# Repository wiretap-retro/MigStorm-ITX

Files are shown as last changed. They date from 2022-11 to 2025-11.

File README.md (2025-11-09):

# MigStorm-ITX
A 68000 socketed ITX form factor Minimig.

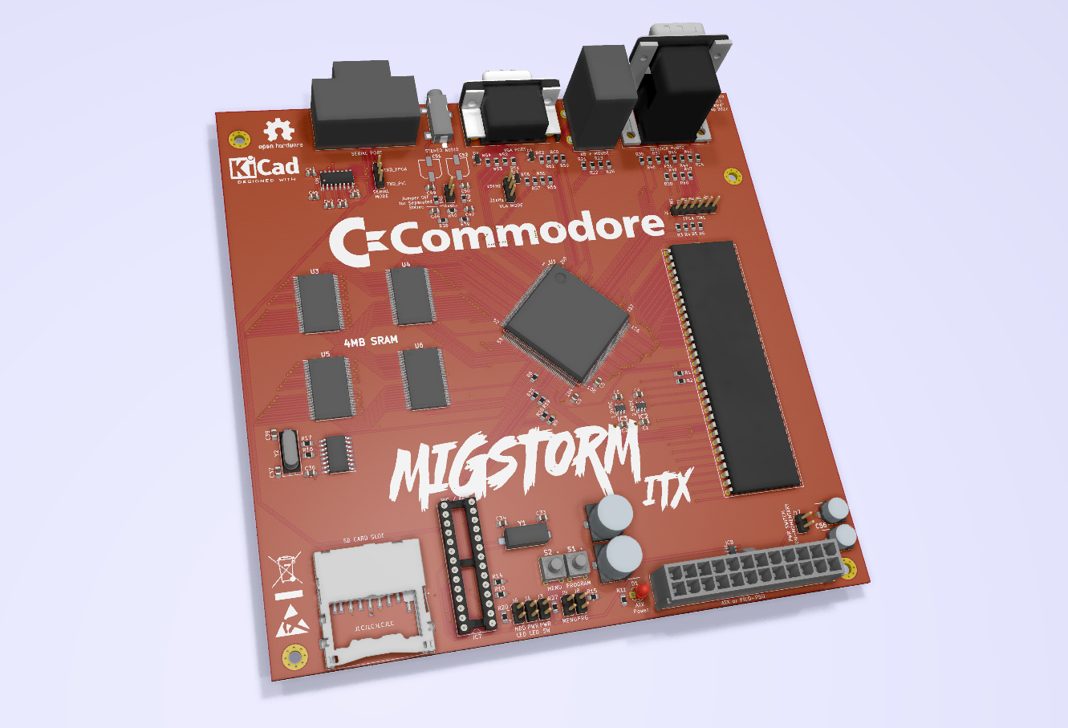
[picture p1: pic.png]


## Info
Tested by Zenon to boot with Pistorm and CaffeineOS, also with a regular M68k CPU. It appears to be fully working, and I've received feedback from at least 10 people that it is working well in their testing. It could use more general trace cleanup/enhancement, but works as-is.

## Mouser Cart
https://www.mouser.com/ProjectManager/ProjectDetail.aspx?AccessID=da74540bb5 \
At the time of making the Mouser cart, all parts were in stock. If parts go out of stock, EOL, have a part number change, or have a minimum order quantity change -- seach for equivalent replacements or they may be able to be sourced from Arrow and Digikey. I recommend using Octopart and other similar sites to search for parts if you can't find something. I caution using sources like Ebay and Aliexpress for key components, especially from China-based sellers with little to no feedback since they'll often sell counterfeit items. Sometimes you get lucky, sometimes you don't. Primary/authorized retailers are highly recommended for component purchases so you do less troubleshooting and can spend more time playing. \
\
As a DIY project, total cost for all parts and a board should come out to just under $150. (plus the cost of a CPU/Pistorm, power supply, and case) \
\
An interactive HTML BOM has been added to the main repository to assist with building.

## Other / Misc. Contributions
jjsaenz1969's 3D printed case for Migstorm: https://www.thingiverse.com/thing:7063501

## Rev History
v0.6 -- Current rev to build. Updated PS/2 Mouse & Keyboard to use redundant clock & data lines due to issues with some keyboards and mice using splitter style pinout. \
v0.5 -- Updated silkscreen for capacitor polarity upon community request. Updated iBOM and BOM. \
v0.4 -- Corrected PS/2 Mouse & Keyboard pwr/gnd pinout. \
v0.3 -- Changed soft-power circuit from 555 timer to a MAX16054, cleaned up a few traces with lots of vias. Still need more cleanup. [depreciated rev, do not build] \
v0.2 -- Initial rev with corrected 68k socket size. [depreciated rev, do not build] \
v0.1 -- Alpha release, incorrect 68k footprint width. [depreciated, removed]

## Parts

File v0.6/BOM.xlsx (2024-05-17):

MigStorm v0.6 Bill of Materials
Reference | Quantity | Value | Footprint | Description | Manufacturer Name | Manufacturer Part Number | Note
C1 C4 C2 C5 | 4 | 1uF X5R | Capacitor_SMD:C_0805_2012Metric_Pad1.15x1.40mm_HandSolder
C14 C16 C18 C20 C13 C15 C17 C19 C3 C6 C7 C8 C9 C10 C11 C12 C23 C24 C46 C47 C49 C50 | 22 | 10nF | Capacitor_SMD:C_0805_2012Metric_Pad1.15x1.40mm_HandSolder
C22 C21 C26 C27 C28 C25 C30 C31 C32 C29 C41 C36 C45 C48 C42 C43 C44 | 17 | 100nF | Capacitor_SMD:C_0805_2012Metric_Pad1.15x1.40mm_HandSolder
C33 C34 | 2 | 47pf | Capacitor_SMD:C_0805_2012Metric_Pad1.15x1.40mm_HandSolder
C37 | 1 | 100pF | Capacitor_SMD:C_0805_2012Metric_Pad1.15x1.40mm_HandSolder
C39 | 1 | 22pF | Capacitor_SMD:C_0805_2012Metric_Pad1.15x1.40mm_HandSolder
C51 C52 | 2 | 16SVT100M | 16SVPT100M | Aluminium Organic Polymer Capacitors 16VDC 100uF 20% 780mA 24mOhm | Panasonic | 16SVT100M
C54 C53 | 2 | 470uF | CAPAE1030X1050N | Wurth Elektronik 470uF 10 V dc Aluminium Electrolytic Capacitor, WCAP-AS5H Series 5000h 10.5 (Dia.) x 9.85mm | Wurth Elektronik | 865230257007
C55 C56 | 2 | 100uF | CAPAE660X550N | Wurth Elektronik 100uF 6.3 V dc Aluminium Electrolytic Capacitor, WCAP-AS5H Series 5000h 5.5 (Dia.) x 6.15mm | Wurth Elektronik | 865230143004
D1 | 1 | BrdPwr | LED_THT:LED_D3.0mm
D6 D5 D2 D3 D4 | 5 | BAV99 | Package_TO_SOT_SMD:SOT-23
IC1 | 1 | SN74HC4060NSR | SOIC127P780X200-16N | 14-Stage Asynchronous Binary Counters And Oscillators | Texas Instruments | SN74HC4060NSR
IC2 | 1 | MIC5504-2.5YM5-TR | SOT95P280X145-5N | LDO Voltage Regulators Single 300mA LDO with Enable Pull-Down & Auto Discharge | Microchip | MIC5504-2.5YM5-TR
IC3 | 1 | TPS731125DBVR | SOT95P280X145-5N | Cap-Free, NMOS, 150mA Low-Dropout (LDO) Regulator With Reverse Current Protection | Texas Instruments | TPS731125DBVR
IC4 IC5 IC6 | 3 | SN74CBTD16210DGGR | SOP50P810X120-48N | SN74CBTD16210DGGR, Bus Switch 74CBT, 10 x 1:1, 4.5 5.5 V 48-Pin TSSOP | Texas Instruments | SN74CBTD16210DGGR
IC7 | 1 | PIC18F26K20-I_SP | Package_DIP:DIP-28_W7.62mm_Socket | Microchip PIC18F26K20-I/SP, 8bit PIC Microcontroller, 64MHz, 64 kB, 1024 B Flash, 28-Pin SPDIP | Microchip | PIC18F26K20-I/SP
IC8 | 1 | MAX16054AZT+T | SOT95P275X110-6N | On Off Controller, Debounce, 15kV ESD MAX16054AZT+T, Voltage Supervisor No Push Button Controller 6-Pin SOT-23 | Maxim Integrated | MAX16054AZT+T
J1 | 1 | JTAG | Connector_PinHeader_2.54mm:PinHeader_1x06_P2.54mm_Vertical
J10 | 1 | Serial | Connector_PinHeader_2.54mm:PinHeader_1x03_P2.54mm_Vertical
J11 | 1 | 500998-0900 | 5009980900 | 9 way normal mount SD card connector 9 way normal mount SD card connector | Molex | 500998-0900
J12 | 1 | Audio | Connector_PinHeader_2.54mm:PinHeader_1x02_P2.54mm_Vertical
J13 | 1 | 178-009-613R571 | 178-009-613R571
J14 | 1 | L77SDE09S1ACO4R | L77SDE09S1ACO4R | D-Sub Standard Connectors Dsub, Stamped Signal 3A, Right Angle PCB Thru Hole, FP=10.40mm (.409in), Row Pitch 2.54mm, 09 Socket, Flash Gold, Bright Tin Shell, 4-40 Rear Insert, Ground Tab with Clear Hole Without Boardlock | Amphenol | L77SDE09S1ACO4R
J15 | 1 | SJ-3523-SMT-TR | SJ3523SMTTR | Phone Connectors Audio Jacks | CUI Inc. | SJ-3523-SMT-TR
J16 | 1 | L77HDE15SD1CH4RHNVGA | L77HDE15SD1CH4RHNVGA | D-Sub High Density Connectors Dsub, Stamped Signal 3A, High Density, Right Angle PCB Thru Hole, FP=8.89mm (.350) | Bright Tin Shell | L77HDE15SD1CH4RHNVGA
J17 | 1 | ON-OFF | Connector_PinHeader_2.54mm:PinHeader_1x02_P2.54mm_Vertical
J2 | 1 | 87427-2442 | 87427-2442 | Mini-Fit Jr. Header, 4.20mm Pitch, Vertical, without Flange, 24 Circuits, Tin (Sn) over Nickel (Ni) Plating, Bulk Packaging | Molex | 87427-2442
J3 | 1 | PWRSWCH | Connector_PinHeader_2.54mm:PinHeader_1x02_P2.54mm_Vertical
J4 | 1 | PWRLED | Connector_PinHeader_2.54mm:PinHeader_1x02_P2.54mm_Vertical
J5 | 1 | Video Mode | Connector_PinHeader_2.54mm:PinHeader_1x03_P2.54mm_Vertical
J6 | 1 | DISKLED | Connector_PinHeader_2.54mm:PinHeader_1x02_P2.54mm_Vertical
J7 | 1 | KMDGX-6S_6S-S4N1 | KMDGX6S6SS4N1 | Circular DIN Connectors MINI-DIN PANEL MNT 6P SNAP&LOCK 1270 W | Kycon | KMDGX-6S/6S-S4N1
J8 | 1 | PROGRAM | Connector_PinHeader_2.54mm:PinHeader_1x02_P2.54mm_Vertical
J9 | 1 | MENU | Connector_PinHeader_2.54mm:PinHeader_1x02_P2.54mm_Vertical
R1 R2 R16 R52 R56 R60 | 6 | 2.2k | Resistor_SMD:R_0805_2012Metric_Pad1.15x1.40mm_HandSolder
R11 R40 R29 R63 R53 R57 R61 | 7 | 1k | Resistor_SMD:R_0805_2012Metric_Pad1.15x1.40mm_HandSolder
R15 R14 R10 R24 R51 R55 R59 | 7 | 4.7k | Resistor_SMD:R_0805_2012Metric_Pad1.15x1.40mm_HandSolder
R17 | 1 | 1M | Resistor_SMD:R_0805_2012Metric_Pad1.15x1.40mm_HandSolder
R19 R20 | 2 | 330 | Resistor_SMD:R_0805_2012Metric_Pad1.15x1.40mm_HandSolder
R3 R4 R6 R5 R33 R65 | 6 | 100 | Resistor_SMD:R_0805_2012Metric_Pad1.15x1.40mm_HandSolder
R38 R39 R41 R42 R54 R58 R62 | 7 | 560 | Resistor_SMD:R_0805_2012Metric_Pad1.15x1.40mm_HandSolder
R64 | 1 | 180 | Resistor_SMD:R_0805_2012Metric_Pad1.15x1.40mm_HandSolder
R7 R8 R9 R25 R26 R27 R21 R22 R28 R23 R43 R44 R45 R46 R34 R35 R36 R37 R47 R48 R49 R50 R30 R31 R32 | 25 | 270 | Resistor_SMD:R_0805_2012Metric_Pad1.15x1.40mm_HandSolder
S1 S2 | 2 | FSM4JH | FSM4JH | 6x6mm tactile switch,5mm H 1.6N Black Button Tactile Switch, SPST-NO 50 mA@ 24 V dc 1.4mm | TE Connectivity | FSM4JH
U1 | 1 | XC3S400-4PQ208C | QFP50P3060X3060X410-208N | FPGA - Field Programmable Gate Array 400000 SYSTEM GATE 1.2 VOLT FPGA | XILINX | XC3S400-4PQ208C
U2 | 1 | 68000D | Package_DIP:DIP-64_W22.86mm_Socket
U3 U5 U4 U6 | 4 | IS62WV51216EBLL-45TLI | SOP80P1176X120-44N | SRAM Chip Async Single 2.5V/3.3V 8M-bit 512K x 16 45ns 44-Pin TSOP-II | Integrated Silicon Solution Inc. | IS62WV51216EBLL-45TLI
U8 | 1 | SP3232EUCN | Package_SO:SOIC-16_3.9x9.9mm_P1.27mm
Y1 | 1 | 20 MHz | LFXTAL020423CUTT | Crystals 20MHz 22pF -20C 70C | IQD | LFXTAL035939Reel
Y2 | 1 | 4.433619 MHz | Crystal:Crystal_SMD_HC49-SD |  |  | ABLS-4.433619MHZ-B4-T

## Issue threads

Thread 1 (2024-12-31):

Unable to load the Core in my MigStorm

jjsaenz1969, 2024-12-31:
Thank you very much for all your work, this project is fantastic.
I have asked JLCPCB to manufacture your board, the BOM I have ordered the one you recommend on GitHub. And the memory and FPGA are from AliExpress.

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

My problem is that with the Pic and Core code you have on GitHub I get a black screen.
Whereas if I try other combinations of files downloaded from other sites it starts to load the Core.
But it never loads the whole Core.

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

To program the pic I use the TL866II programmer with this combination of fuses.

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

The file ‘firstflash_bootloader+KGL140914.hex’ you have on Github is empty, it would be nice if you can put the correct one.

Let's see if I can get this new Amiga working.

wiretap-retro, 2024-12-31:
You're going to want to use the tinybld198 folder for generating the PIC's firmware to flash with the firmware.hex file. The KGL140914 is for the SuperPIC. I've updated the firmware folder to include all variants of the PIC/SuperPIC/ARM modules.

jjsaenz1969, 2024-12-31:
Thank you for your prompt response.
I have the SuperPIC, then I will try what you have posted on Github.
Hopefully we'll finish this year with one more Amiga.

jjsaenz1969, 2025-01-18:
Thank you for your advice.
I had a hard time finding it, but I remembered I had one.
I've never used it before, it was easy.

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

I was able to burn the chip with the file ‘firstflash_bootloader+KGL140914.hex’, but the result is the same.
It loads the Core but does not start the Minimig.

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

The PacMan Core works perfectly, so I have a fault in the RAM or in the CPU.

Next I'll remove the CPU socket and check the chips underneath.

wiretap-retro, 2025-01-19:
Yeah you'll want to check all orientations of the chips, and use a small sewing needle to wiggle each leg of each chip to make sure they are all soldered down right. Also check for bridges between legs. Sometimes they're really hard to spot without good magnification.

jjsaenz1969, 2025-01-31:
I have good news.

I have checked the chips that are under the CPU, for this I created a new interactive BOM, but indicating that it shows the pads and tracks.
All correct there.
I also bought new RAM, this is from Mouser, the one I had before I bought from Aliexpress.

The unsoldered chip is Mouser's.
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

I have also checked every pin on the FPGA and everything is OK.
It's always the same, it always freezes at the same point.

My PIStorm is not the normal one, it is an edition that was made in a Spanish forum, it is a bit displaced so as not to touch with the keyboard on an A500.
I couldn't put it directly on the MigStorm as it clashed with the PicoPSU.
Today I got a CPU relocator, I just put it in, plugged my PIStorm and it started working.

The ARM module also works.

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

Everything works very well, I'm very happy.
But I don't know why my MigStorm only works if it has a PIStorm on it.
I don't have a different accelerator to test.

wiretap-retro, 2025-01-31:
I'm so glad to see you got it working. That's very good news. Hopefully you enjoy it!

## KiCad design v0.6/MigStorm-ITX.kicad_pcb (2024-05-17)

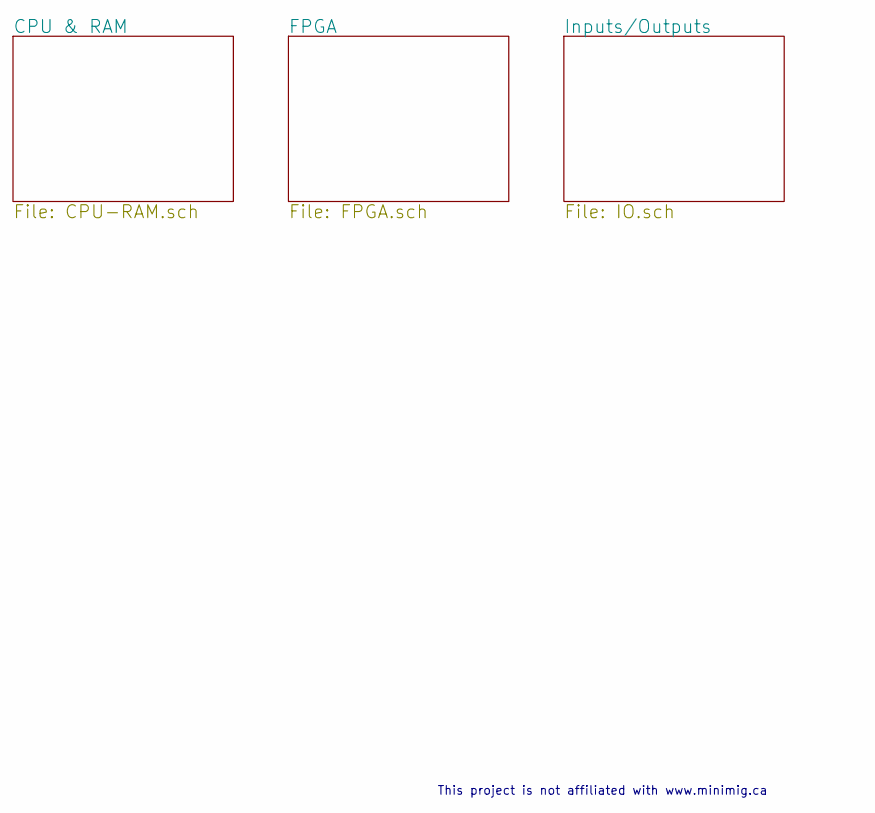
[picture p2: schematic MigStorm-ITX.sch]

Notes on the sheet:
This project is not affiliated with www.minimig.ca

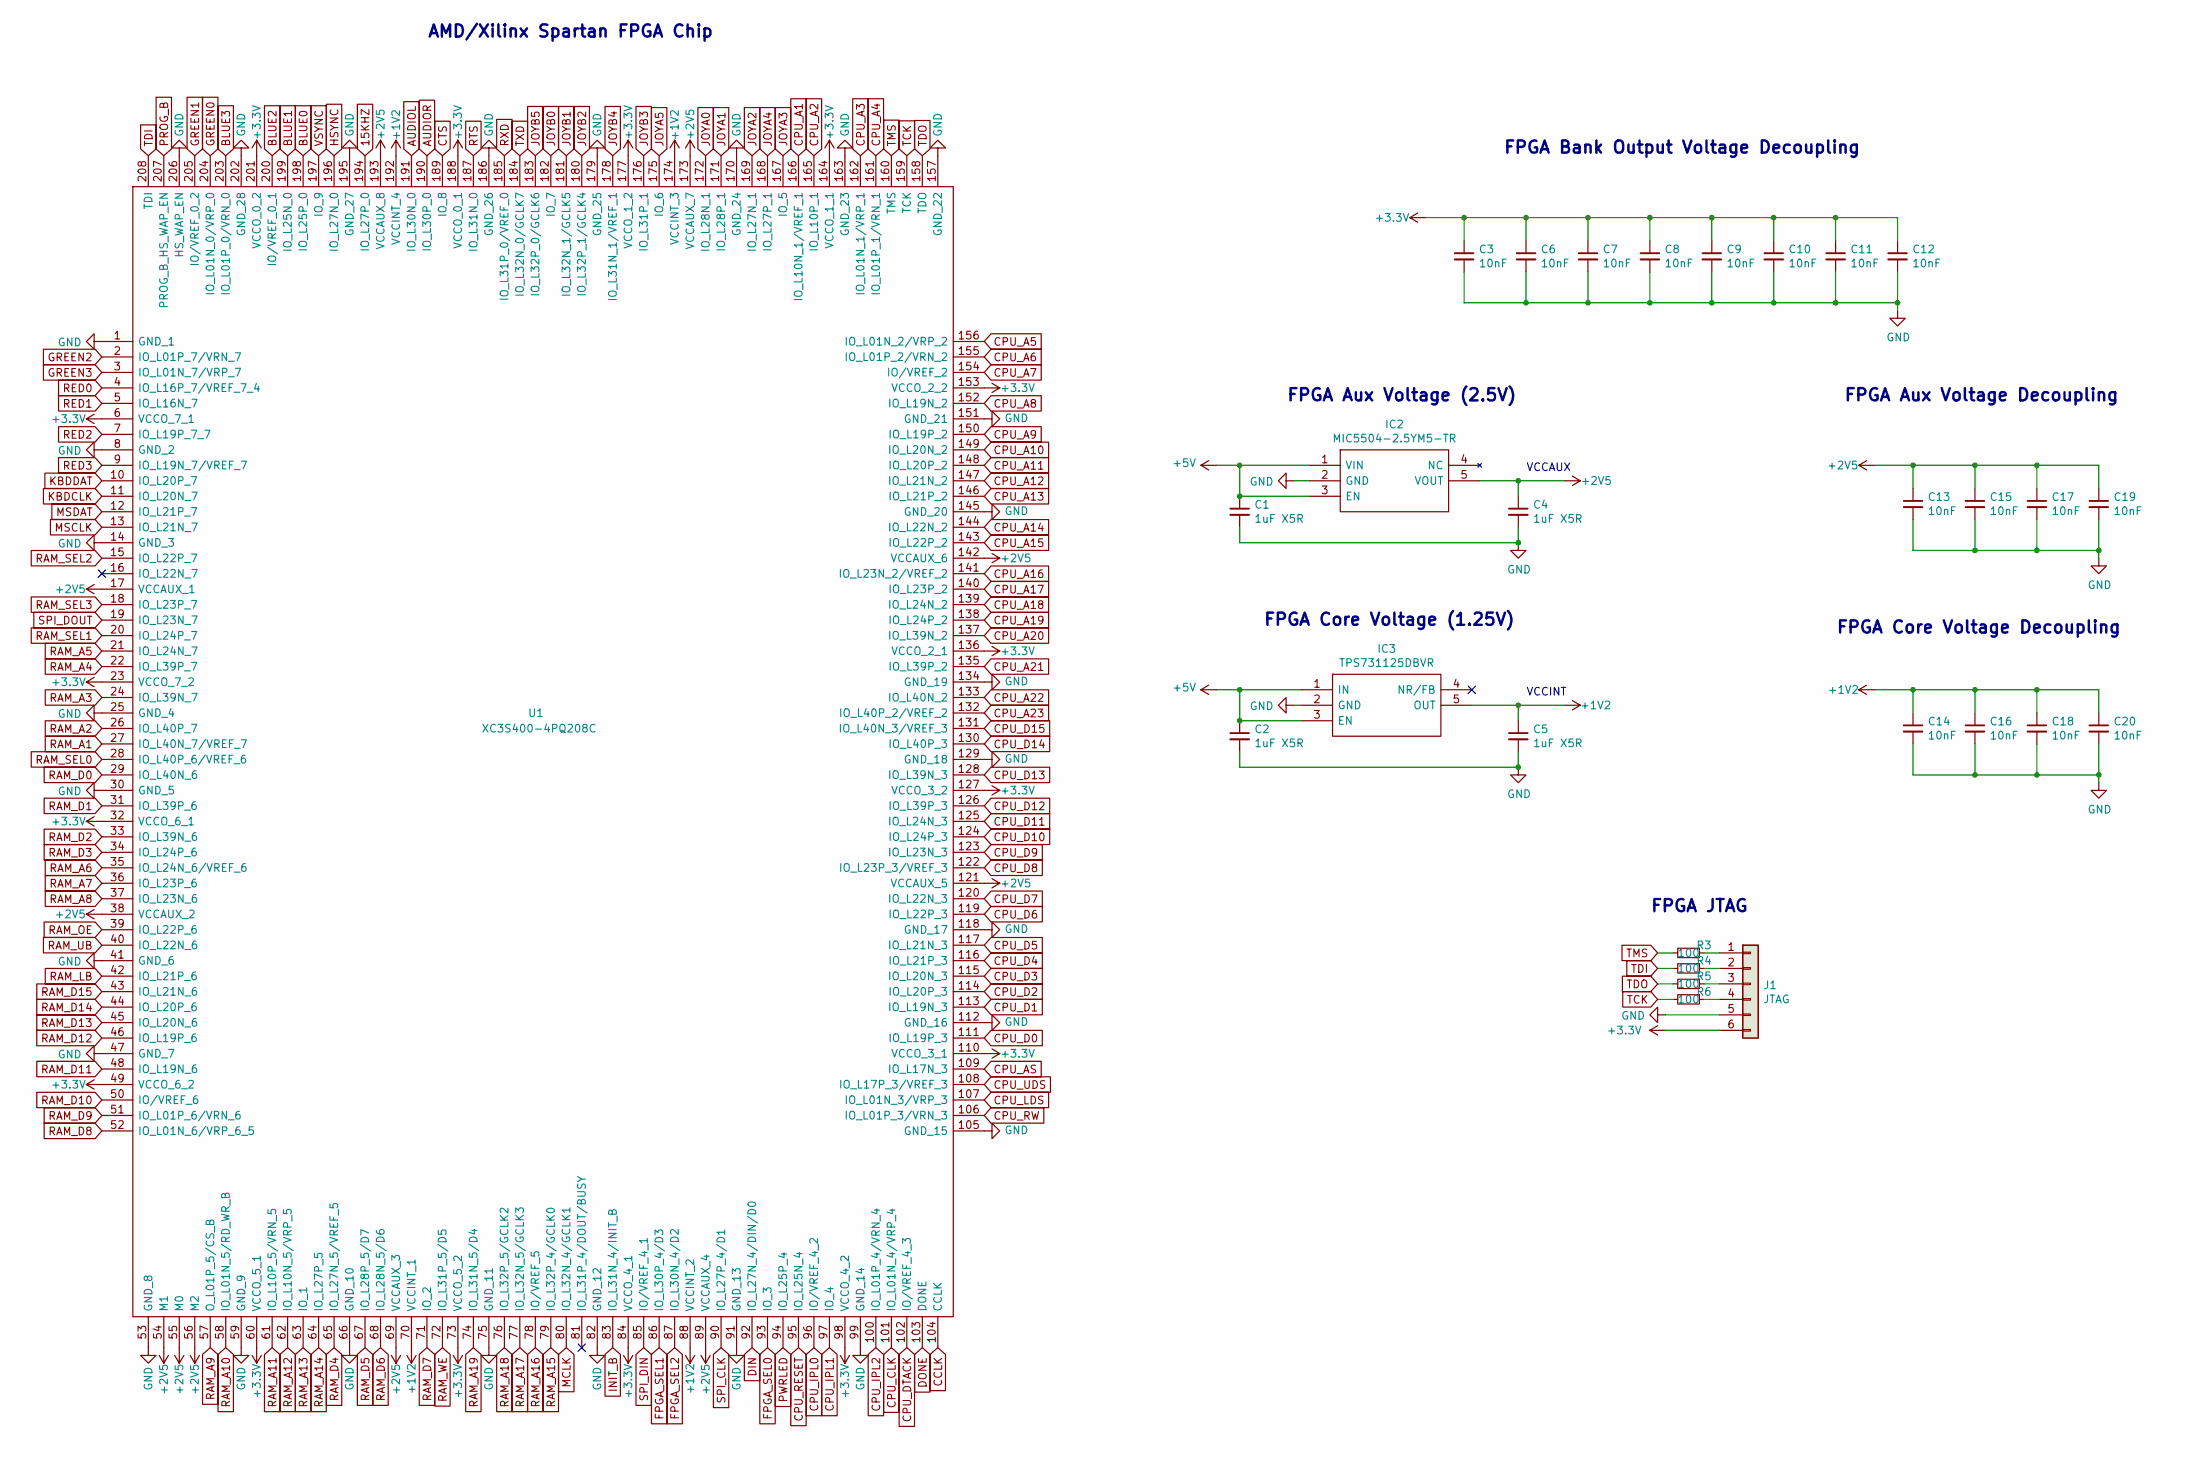
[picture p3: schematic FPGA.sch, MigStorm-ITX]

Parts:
C1, C2, C4, C5: 1uF X5R; C_0805_2012Metric_Pad1.15x1.40mm_HandSolder
C3, C6, C7, C8, C9, C10, C11, C12, C13, C14, C15, C16, C17, C18, C19, C20: 10nF; C_0805_2012Metric_Pad1.15x1.40mm_HandSolder
IC2: MIC5504-2.5YM5-TR; SOT95P280X145-5N; Mouser Part Number 998-MIC5504-2.5YM5TR
IC3: TPS731125DBVR; SOT95P280X145-5N; Mouser Part Number 595-TPS731125DBVR
J1: JTAG; PinHeader_1x06_P2.54mm_Vertical
R3, R4, R5, R6: 100; R_0805_2012Metric_Pad1.15x1.40mm_HandSolder
U1: XC3S400-4PQ208C; QFP50P3060X3060X410-208N; Mouser Part Number 217-XC3S400-4PQ208C

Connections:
3.3V: C3.1, C6.1, C7.1, C8.1, C9.1, C10.1, C11.1, C12.1, J1.6, U1.6 (VCCO_7_1), U1.23 (VCCO_7_2), U1.32 (VCCO_6_1), U1.49 (VCCO_6_2), U1.60 (VCCO_5_1), U1.73 (VCCO_5_2), U1.84 (VCCO_4_1), U1.98 (VCCO_4_2), U1.110 (VCCO_3_1), U1.127 (VCCO_3_2), U1.136 (VCCO_2_1), U1.153 (VCCO_2_2), U1.164 (VCCO_1_1), U1.177 (VCCO_1_2), U1.188 (VCCO_0_1), U1.201 (VCCO_0_2); also elsewhere on the board
5VDC: C1.1, C2.1, IC2.1 (VIN), IC2.3 (EN), IC3.1 (IN), IC3.3 (EN); also elsewhere on the board
15KHZ: U1.194 (IO_L27P_0); also elsewhere on the board
+1V2: C5.1, C14.1, C16.1, C18.1, C20.1, IC3.5 (OUT), U1.70 (VCCINT_1), U1.88 (VCCINT_2), U1.174 (VCCINT_3), U1.192 (VCCINT_4)
+2V5: C4.1, C13.1, C15.1, C17.1, C19.1, IC2.5 (VOUT), U1.17 (VCCAUX_1), U1.38 (VCCAUX_2), U1.54 (M1), U1.55 (M0), U1.56 (M2), U1.69 (VCCAUX_3), U1.89 (VCCAUX_4), U1.121 (VCCAUX_5), U1.142 (VCCAUX_6), U1.173 (VCCAUX_7), U1.193 (VCCAUX_8)
AUDIOL: U1.191 (IO_L30N_0); also elsewhere on the board
AUDIOR: U1.190 (IO_L30P_0); also elsewhere on the board
BLUE0: U1.198 (IO_L25P_0); also elsewhere on the board
BLUE1: U1.199 (IO_L25N_0); also elsewhere on the board
BLUE2: U1.200 (IO/VREF_0_1); also elsewhere on the board
BLUE3: U1.203 (IO_L01P_0/VRN_0); also elsewhere on the board
CCLK: U1.104 (CCLK); also elsewhere on the board
CPU_A1: U1.166 (IO_L10N_1/VREF_1); also elsewhere on the board
CPU_A2: U1.165 (IO_L10P_1); also elsewhere on the board
CPU_A3: U1.162 (IO_L01N_1/VRP_1); also elsewhere on the board
CPU_A4: U1.161 (IO_L01P_1/VRN_1); also elsewhere on the board
CPU_A5: U1.156 (IO_L01N_2/VRP_2); also elsewhere on the board
CPU_A6: U1.155 (IO_L01P_2/VRN_2); also elsewhere on the board
CPU_A7: U1.154 (IO/VREF_2); also elsewhere on the board
CPU_A8: U1.152 (IO_L19N_2); also elsewhere on the board
CPU_A9: U1.150 (IO_L19P_2); also elsewhere on the board
CPU_A10: U1.149 (IO_L20N_2); also elsewhere on the board
CPU_A11: U1.148 (IO_L20P_2); also elsewhere on the board
CPU_A12: U1.147 (IO_L21N_2); also elsewhere on the board
CPU_A13: U1.146 (IO_L21P_2); also elsewhere on the board
CPU_A14: U1.144 (IO_L22N_2); also elsewhere on the board
CPU_A15: U1.143 (IO_L22P_2); also elsewhere on the board
CPU_A16: U1.141 (IO_L23N_2/VREF_2); also elsewhere on the board
CPU_A17: U1.140 (IO_L23P_2); also elsewhere on the board
CPU_A18: U1.139 (IO_L24N_2); also elsewhere on the board
CPU_A19: U1.138 (IO_L24P_2); also elsewhere on the board
CPU_A20: U1.137 (IO_L39N_2); also elsewhere on the board
CPU_A21: U1.135 (IO_L39P_2); also elsewhere on the board
CPU_A22: U1.133 (IO_L40N_2); also elsewhere on the board
CPU_A23: U1.132 (IO_L40P_2/VREF_2); also elsewhere on the board
CPU_AS: U1.109 (IO_L17N_3); also elsewhere on the board
CPU_CLK: U1.101 (IO_L01N_4/VRP_4); also elsewhere on the board
CPU_D0: U1.111 (IO_L19P_3); also elsewhere on the board
CPU_D1: U1.113 (IO_L19N_3); also elsewhere on the board
CPU_D2: U1.114 (IO_L20P_3); also elsewhere on the board
CPU_D3: U1.115 (IO_L20N_3); also elsewhere on the board
CPU_D4: U1.116 (IO_L21P_3); also elsewhere on the board
CPU_D5: U1.117 (IO_L21N_3); also elsewhere on the board
CPU_D6: U1.119 (IO_L22P_3); also elsewhere on the board
CPU_D7: U1.120 (IO_L22N_3); also elsewhere on the board
CPU_D8: U1.122 (IO_L23P_3/VREF_3); also elsewhere on the board
CPU_D9: U1.123 (IO_L23N_3); also elsewhere on the board
CPU_D10: U1.124 (IO_L24P_3); also elsewhere on the board
CPU_D11: U1.125 (IO_L24N_3); also elsewhere on the board
CPU_D12: U1.126 (IO_L39P_3); also elsewhere on the board
CPU_D13: U1.128 (IO_L39N_3); also elsewhere on the board
CPU_D14: U1.130 (IO_L40P_3); also elsewhere on the board
CPU_D15: U1.131 (IO_L40N_3/VREF_3); also elsewhere on the board
CPU_DTACK: U1.102 (IO/VREF_4_3); also elsewhere on the board
CPU_IPL0: U1.96 (IO/VREF_4_2); also elsewhere on the board
CPU_IPL1: U1.97 (IO_4); also elsewhere on the board
CPU_IPL2: U1.100 (IO_L01P_4/VRN_4); also elsewhere on the board
CPU_LDS: U1.107 (IO_L01N_3/VRP_3); also elsewhere on the board
CPU_RESET: U1.95 (IO_L25N_4); also elsewhere on the board
CPU_RW: U1.106 (IO_L01P_3/VRN_3); also elsewhere on the board
CPU_UDS: U1.108 (IO_L17P_3/VREF_3); also elsewhere on the board
CTS: U1.189 (IO_8); also elsewhere on the board
DIN: U1.92 (IO_L27N_4/DIN/D0); also elsewhere on the board
DONE: U1.103 (DONE); also elsewhere on the board
FPGA_SEL0: U1.93 (IO_3); also elsewhere on the board
FPGA_SEL1: U1.86 (IO_L30P_4/D3); also elsewhere on the board
FPGA_SEL2: U1.87 (IO_L30N_4/D2); also elsewhere on the board
GND: C1.2, C2.2, C3.2, C4.2, C5.2, C6.2, C7.2, C8.2, C9.2, C10.2, C11.2, C12.2, C13.2, C14.2, C15.2, C16.2, C17.2, C18.2, C19.2, C20.2, IC2.2 (GND), IC3.2 (GND), J1.5, U1.1 (GND_1), U1.8 (GND_2), U1.14 (GND_3), U1.25 (GND_4), U1.30 (GND_5), U1.41 (GND_6), U1.47 (GND_7), U1.53 (GND_8), U1.59 (GND_9), U1.66 (GND_10), U1.75 (GND_11), U1.82 (GND_12), U1.91 (GND_13), U1.99 (GND_14), U1.105 (GND_15), U1.112 (GND_16), U1.118 (GND_17), U1.129 (GND_18), U1.134 (GND_19), U1.145 (GND_20), U1.151 (GND_21), U1.157 (GND_22), U1.163 (GND_23), U1.170 (GND_24), U1.179 (GND_25), U1.186 (GND_26), U1.195 (GND_27), U1.202 (GND_28), U1.206 (HS_WAP_EN); also elsewhere on the board
GREEN0: U1.204 (IO_L01N_0/VRP_0); also elsewhere on the board
GREEN1: U1.205 (IO/VREF_0_2); also elsewhere on the board
GREEN2: U1.2 (IO_L01P_7/VRN_7); also elsewhere on the board
GREEN3: U1.3 (IO_L01N_7/VRP_7); also elsewhere on the board
HSYNC: U1.196 (IO_L27N_0); also elsewhere on the board
INIT_B: U1.83 (IO_L31N_4/INIT_B); also elsewhere on the board
JOYA0: U1.172 (IO_L28N_1); also elsewhere on the board
JOYA1: U1.171 (IO_L28P_1); also elsewhere on the board
JOYA2: U1.169 (IO_L27N_1); also elsewhere on the board
JOYA3: U1.167 (IO_5); also elsewhere on the board
JOYA4: U1.168 (IO_L27P_1); also elsewhere on the board
JOYA5: U1.175 (IO_6); also elsewhere on the board
JOYB0: U1.182 (IO_7); also elsewhere on the board
JOYB1: U1.181 (IO_L32N_1/GCLK5); also elsewhere on the board
JOYB2: U1.180 (IO_L32P_1/GCLK4); also elsewhere on the board
JOYB3: U1.176 (IO_L31P_1); also elsewhere on the board
JOYB4: U1.178 (IO_L31N_1/VREF_1); also elsewhere on the board
JOYB5: U1.183 (IO_L32P_0/GCLK6); also elsewhere on the board
KBDCLK: U1.11 (IO_L20N_7); also elsewhere on the board
KBDDAT: U1.10 (IO_L20P_7); also elsewhere on the board
MCLK: U1.80 (IO_L32N_4/GCLK1); also elsewhere on the board
MSCLK: U1.13 (IO_L21N_7); also elsewhere on the board
MSDAT: U1.12 (IO_L21P_7); also elsewhere on the board
unnamed: J1.1, R3.1
unnamed: J1.2, R4.1
unnamed: J1.3, R5.1
unnamed: J1.4, R6.1
PROG_B: U1.207 (PROG_B_HS_WAP_EN); also elsewhere on the board
PWRLED: U1.94 (IO_L25P_4); also elsewhere on the board
RAM_A1: U1.27 (IO_L40N_7/VREF_7); also elsewhere on the board
RAM_A2: U1.26 (IO_L40P_7); also elsewhere on the board
RAM_A3: U1.24 (IO_L39N_7); also elsewhere on the board
RAM_A4: U1.22 (IO_L39P_7); also elsewhere on the board
RAM_A5: U1.21 (IO_L24N_7); also elsewhere on the board
RAM_A6: U1.35 (IO_L24N_6/VREF_6); also elsewhere on the board
RAM_A7: U1.36 (IO_L23P_6); also elsewhere on the board
RAM_A8: U1.37 (IO_L23N_6); also elsewhere on the board
RAM_A9: U1.57 (O_L01P_5/CS_B); also elsewhere on the board
RAM_A10: U1.58 (IO_L01N_5/RD_WR_B); also elsewhere on the board
RAM_A11: U1.61 (IO_L10P_5/VRN_5); also elsewhere on the board
RAM_A12: U1.62 (IO_L10N_5/VRP_5); also elsewhere on the board
RAM_A13: U1.63 (IO_1); also elsewhere on the board
RAM_A14: U1.64 (IO_L27P_5); also elsewhere on the board
RAM_A15: U1.79 (IO_L32P_4/GCLK0); also elsewhere on the board
RAM_A16: U1.78 (IO/VREF_5); also elsewhere on the board
RAM_A17: U1.77 (IO_L32N_5/GCLK3); also elsewhere on the board
RAM_A18: U1.76 (IO_L32P_5/GCLK2); also elsewhere on the board
RAM_A19: U1.74 (IO_L31N_5/D4); also elsewhere on the board
RAM_D0: U1.29 (IO_L40N_6); also elsewhere on the board
RAM_D1: U1.31 (IO_L39P_6); also elsewhere on the board
RAM_D2: U1.33 (IO_L39N_6); also elsewhere on the board
RAM_D3: U1.34 (IO_L24P_6); also elsewhere on the board
RAM_D4: U1.65 (IO_L27N_5/VREF_5); also elsewhere on the board
RAM_D5: U1.67 (IO_L28P_5/D7); also elsewhere on the board
RAM_D6: U1.68 (IO_L28N_5/D6); also elsewhere on the board
RAM_D7: U1.71 (IO_2); also elsewhere on the board
RAM_D8: U1.52 (IO_L01N_6/VRP_6_5); also elsewhere on the board
RAM_D9: U1.51 (IO_L01P_6/VRN_6); also elsewhere on the board
RAM_D10: U1.50 (IO/VREF_6); also elsewhere on the board
RAM_D11: U1.48 (IO_L19N_6); also elsewhere on the board
RAM_D12: U1.46 (IO_L19P_6); also elsewhere on the board
RAM_D13: U1.45 (IO_L20N_6); also elsewhere on the board
RAM_D14: U1.44 (IO_L20P_6); also elsewhere on the board
RAM_D15: U1.43 (IO_L21N_6); also elsewhere on the board
RAM_LB: U1.42 (IO_L21P_6); also elsewhere on the board
RAM_OE: U1.39 (IO_L22P_6); also elsewhere on the board
RAM_SEL0: U1.28 (IO_L40P_6/VREF_6); also elsewhere on the board
RAM_SEL1: U1.20 (IO_L24P_7); also elsewhere on the board
RAM_SEL2: U1.15 (IO_L22P_7); also elsewhere on the board
RAM_SEL3: U1.18 (IO_L23P_7); also elsewhere on the board
RAM_UB: U1.40 (IO_L22N_6); also elsewhere on the board
RAM_WE: U1.72 (IO_L31P_5/D5); also elsewhere on the board
RED0: U1.4 (IO_L16P_7/VREF_7_4); also elsewhere on the board
RED1: U1.5 (IO_L16N_7); also elsewhere on the board
RED2: U1.7 (IO_L19P_7_7); also elsewhere on the board
RED3: U1.9 (IO_L19N_7/VREF_7); also elsewhere on the board
RTS: U1.187 (IO_L31N_0); also elsewhere on the board
RXD: U1.185 (IO_L31P_0/VREF_0); also elsewhere on the board
SPI_CLK: U1.90 (IO_L27P_4/D1); also elsewhere on the board
SPI_DIN: U1.85 (IO/VREF_4_1); also elsewhere on the board
SPI_DOUT: U1.19 (IO_L23N_7); also elsewhere on the board
TCK: R6.2, U1.159 (TCK)
TDI: R4.2, U1.208 (TDI)
TDO: R5.2, U1.158 (TDO)
TMS: R3.2, U1.160 (TMS)
TXD: U1.184 (IO_L32N_0/GCLK7); also elsewhere on the board
VSYNC: U1.197 (IO_9); also elsewhere on the board

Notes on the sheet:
AMD/Xilinx Spartan FPGA Chip
FPGA JTAG
FPGA Aux Voltage (2.5V)
FPGA Core Voltage (1.25V)
VCCAUX
VCCINT
FPGA Bank Output Voltage Decoupling
FPGA Aux Voltage Decoupling
FPGA Core Voltage Decoupling

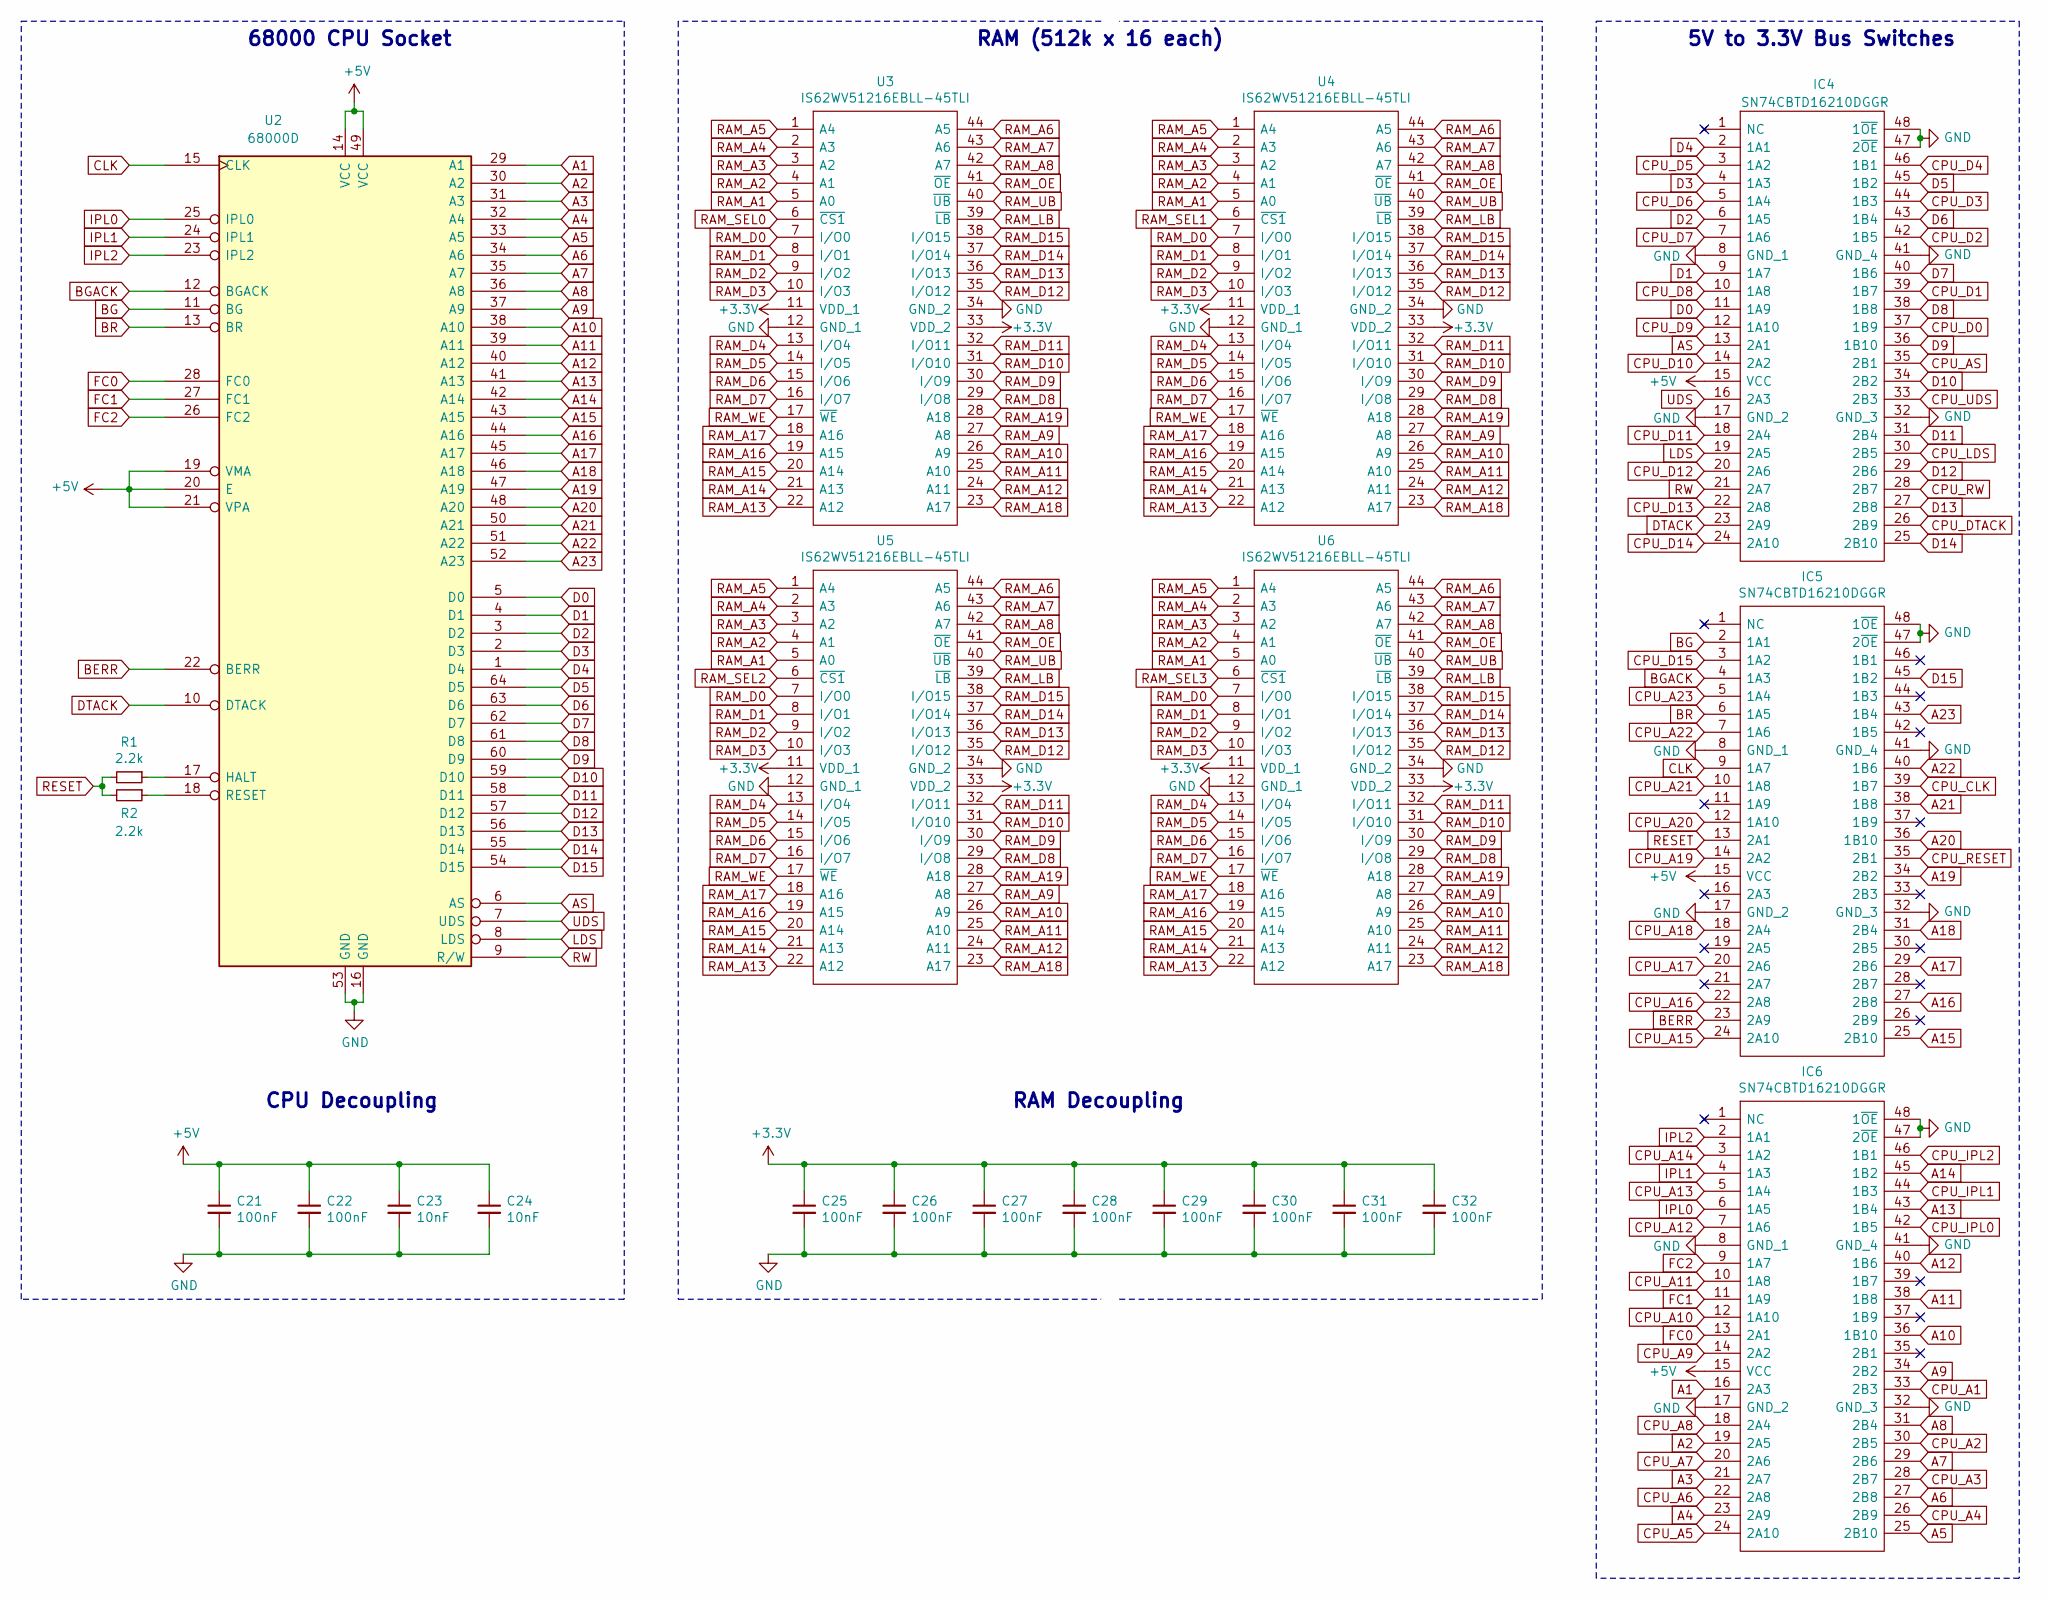
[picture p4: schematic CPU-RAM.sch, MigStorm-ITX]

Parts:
C21, C22, C25, C26, C27, C28, C29, C30, C31, C32: 100nF; C_0805_2012Metric_Pad1.15x1.40mm_HandSolder
C23, C24: 10nF; C_0805_2012Metric_Pad1.15x1.40mm_HandSolder
IC4, IC5, IC6: SN74CBTD16210DGGR; SOP50P810X120-48N; Mouser Part Number 595-74CBTD16210DGGR
R1, R2: 2.2k; R_0805_2012Metric_Pad1.15x1.40mm_HandSolder
U2: 68000D; DIP-64_W22.86mm_Socket
U3, U4, U5, U6: IS62WV51216EBLL-45TLI; SOP80P1176X120-44N; Mouser Part Number 870-62WV512EBLL45TLI

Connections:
3.3V: C25.1, C26.1, C27.1, C28.1, C29.1, C30.1, C31.1, C32.1, U3.11 (VDD_1), U3.33 (VDD_2), U4.11 (VDD_1), U4.33 (VDD_2), U5.11 (VDD_1), U5.33 (VDD_2), U6.11 (VDD_1), U6.33 (VDD_2); also elsewhere on the board
5VDC: C21.1, C22.1, C23.1, C24.1, IC4.15 (VCC), IC5.15 (VCC), IC6.15 (VCC), U2.14 (VCC), U2.19 (VMA), U2.20 (E), U2.21 (VPA), U2.49 (VCC); also elsewhere on the board
A1: IC6.16 (2A3), U2.29 (A1)
A2: IC6.19 (2A5), U2.30 (A2)
A3: IC6.21 (2A7), U2.31 (A3)
A4: IC6.23 (2A9), U2.32 (A4)
A5: IC6.25 (2B10), U2.33 (A5)
A6: IC6.27 (2B8), U2.34 (A6)
A7: IC6.29 (2B6), U2.35 (A7)
A8: IC6.31 (2B4), U2.36 (A8)
A9: IC6.34 (2B2), U2.37 (A9)
A10: IC6.36 (1B10), U2.38 (A10)
A11: IC6.38 (1B8), U2.39 (A11)
A12: IC6.40 (1B6), U2.40 (A12)
A13: IC6.43 (1B4), U2.41 (A13)
A14: IC6.45 (1B2), U2.42 (A14)
A15: IC5.25 (2B10), U2.43 (A15)
A16: IC5.27 (2B8), U2.44 (A16)
A17: IC5.29 (2B6), U2.45 (A17)
A18: IC5.31 (2B4), U2.46 (A18)
A19: IC5.34 (2B2), U2.47 (A19)
A20: IC5.36 (1B10), U2.48 (A20)
A21: IC5.38 (1B8), U2.50 (A21)
A22: IC5.40 (1B6), U2.51 (A22)
A23: IC5.43 (1B4), U2.52 (A23)
AS: IC4.13 (2A1), U2.6 (AS)
BERR: IC5.23 (2A9), U2.22 (BERR)
BG: IC5.2 (1A1), U2.11 (BG)
BGACK: IC5.4 (1A3), U2.12 (BGACK)
BR: IC5.6 (1A5), U2.13 (BR)
CLK: IC5.9 (1A7), U2.15 (CLK)
CPU_A1: IC6.33 (2B3); also elsewhere on the board
CPU_A2: IC6.30 (2B5); also elsewhere on the board
CPU_A3: IC6.28 (2B7); also elsewhere on the board
CPU_A4: IC6.26 (2B9); also elsewhere on the board
CPU_A5: IC6.24 (2A10); also elsewhere on the board
CPU_A6: IC6.22 (2A8); also elsewhere on the board
CPU_A7: IC6.20 (2A6); also elsewhere on the board
CPU_A8: IC6.18 (2A4); also elsewhere on the board
CPU_A9: IC6.14 (2A2); also elsewhere on the board
CPU_A10: IC6.12 (1A10); also elsewhere on the board
CPU_A11: IC6.10 (1A8); also elsewhere on the board
CPU_A12: IC6.7 (1A6); also elsewhere on the board
CPU_A13: IC6.5 (1A4); also elsewhere on the board
CPU_A14: IC6.3 (1A2); also elsewhere on the board
CPU_A15: IC5.24 (2A10); also elsewhere on the board
CPU_A16: IC5.22 (2A8); also elsewhere on the board
CPU_A17: IC5.20 (2A6); also elsewhere on the board
CPU_A18: IC5.18 (2A4); also elsewhere on the board
CPU_A19: IC5.14 (2A2); also elsewhere on the board
CPU_A20: IC5.12 (1A10); also elsewhere on the board
CPU_A21: IC5.10 (1A8); also elsewhere on the board
CPU_A22: IC5.7 (1A6); also elsewhere on the board
CPU_A23: IC5.5 (1A4); also elsewhere on the board
CPU_AS: IC4.35 (2B1); also elsewhere on the board
CPU_CLK: IC5.39 (1B7); also elsewhere on the board
CPU_D0: IC4.37 (1B9); also elsewhere on the board
CPU_D1: IC4.39 (1B7); also elsewhere on the board
CPU_D2: IC4.42 (1B5); also elsewhere on the board
CPU_D3: IC4.44 (1B3); also elsewhere on the board
CPU_D4: IC4.46 (1B1); also elsewhere on the board
CPU_D5: IC4.3 (1A2); also elsewhere on the board
CPU_D6: IC4.5 (1A4); also elsewhere on the board
CPU_D7: IC4.7 (1A6); also elsewhere on the board
CPU_D8: IC4.10 (1A8); also elsewhere on the board
CPU_D9: IC4.12 (1A10); also elsewhere on the board
CPU_D10: IC4.14 (2A2); also elsewhere on the board
CPU_D11: IC4.18 (2A4); also elsewhere on the board
CPU_D12: IC4.20 (2A6); also elsewhere on the board
CPU_D13: IC4.22 (2A8); also elsewhere on the board
CPU_D14: IC4.24 (2A10); also elsewhere on the board
CPU_D15: IC5.3 (1A2); also elsewhere on the board
CPU_DTACK: IC4.26 (2B9); also elsewhere on the board
CPU_IPL0: IC6.42 (1B5); also elsewhere on the board
CPU_IPL1: IC6.44 (1B3); also elsewhere on the board
CPU_IPL2: IC6.46 (1B1); also elsewhere on the board
CPU_LDS: IC4.30 (2B5); also elsewhere on the board
CPU_RESET: IC5.35 (2B1); also elsewhere on the board
CPU_RW: IC4.28 (2B7); also elsewhere on the board
CPU_UDS: IC4.33 (2B3); also elsewhere on the board
D0: IC4.11 (1A9), U2.5 (D0)
D1: IC4.9 (1A7), U2.4 (D1)
D2: IC4.6 (1A5), U2.3 (D2)
D3: IC4.4 (1A3), U2.2 (D3)
D4: IC4.2 (1A1), U2.1 (D4)
D5: IC4.45 (1B2), U2.64 (D5)
D6: IC4.43 (1B4), U2.63 (D6)
D7: IC4.40 (1B6), U2.62 (D7)
D8: IC4.38 (1B8), U2.61 (D8)
D9: IC4.36 (1B10), U2.60 (D9)
D10: IC4.34 (2B2), U2.59 (D10)
D11: IC4.31 (2B4), U2.58 (D11)
D12: IC4.29 (2B6), U2.57 (D12)
D13: IC4.27 (2B8), U2.56 (D13)
D14: IC4.25 (2B10), U2.55 (D14)
D15: IC5.45 (1B2), U2.54 (D15)
DTACK: IC4.23 (2A9), U2.10 (DTACK)
FC0: IC6.13 (2A1), U2.28 (FC0)
FC1: IC6.11 (1A9), U2.27 (FC1)
FC2: IC6.9 (1A7), U2.26 (FC2)
GND: C21.2, C22.2, C23.2, C24.2, C25.2, C26.2, C27.2, C28.2, C29.2, C30.2, C31.2, C32.2, IC4.8 (GND_1), IC4.17 (GND_2), IC4.32 (GND_3), IC4.41 (GND_4), IC4.47 (2~OE), IC4.48 (1~OE), IC5.8 (GND_1), IC5.17 (GND_2), IC5.32 (GND_3), IC5.41 (GND_4), IC5.47 (2~OE), IC5.48 (1~OE), IC6.8 (GND_1), IC6.17 (GND_2), IC6.32 (GND_3), IC6.41 (GND_4), IC6.47 (2~OE), IC6.48 (1~OE), U2.16 (GND), U2.53 (GND), U3.12 (GND_1), U3.34 (GND_2), U4.12 (GND_1), U4.34 (GND_2), U5.12 (GND_1), U5.34 (GND_2), U6.12 (GND_1), U6.34 (GND_2); also elsewhere on the board
IPL0: IC6.6 (1A5), U2.25 (IPL0)
IPL1: IC6.4 (1A3), U2.24 (IPL1)
IPL2: IC6.2 (1A1), U2.23 (IPL2)
LDS: IC4.19 (2A5), U2.8 (LDS)
unnamed: R1.1, U2.17 (HALT)
unnamed: R2.1, U2.18 (RESET)
RAM_A1: U3.5 (A0), U4.5 (A0), U5.5 (A0), U6.5 (A0); also elsewhere on the board
RAM_A2: U3.4 (A1), U4.4 (A1), U5.4 (A1), U6.4 (A1); also elsewhere on the board
RAM_A3: U3.3 (A2), U4.3 (A2), U5.3 (A2), U6.3 (A2); also elsewhere on the board
RAM_A4: U3.2 (A3), U4.2 (A3), U5.2 (A3), U6.2 (A3); also elsewhere on the board
RAM_A5: U3.1 (A4), U4.1 (A4), U5.1 (A4), U6.1 (A4); also elsewhere on the board
RAM_A6: U3.44 (A5), U4.44 (A5), U5.44 (A5), U6.44 (A5); also elsewhere on the board
RAM_A7: U3.43 (A6), U4.43 (A6), U5.43 (A6), U6.43 (A6); also elsewhere on the board
RAM_A8: U3.42 (A7), U4.42 (A7), U5.42 (A7), U6.42 (A7); also elsewhere on the board
RAM_A9: U3.27 (A8), U4.27 (A8), U5.27 (A8), U6.27 (A8); also elsewhere on the board
RAM_A10: U3.26 (A9), U4.26 (A9), U5.26 (A9), U6.26 (A9); also elsewhere on the board
RAM_A11: U3.25 (A10), U4.25 (A10), U5.25 (A10), U6.25 (A10); also elsewhere on the board
RAM_A12: U3.24 (A11), U4.24 (A11), U5.24 (A11), U6.24 (A11); also elsewhere on the board
RAM_A13: U3.22 (A12), U4.22 (A12), U5.22 (A12), U6.22 (A12); also elsewhere on the board
RAM_A14: U3.21 (A13), U4.21 (A13), U5.21 (A13), U6.21 (A13); also elsewhere on the board
RAM_A15: U3.20 (A14), U4.20 (A14), U5.20 (A14), U6.20 (A14); also elsewhere on the board
RAM_A16: U3.19 (A15), U4.19 (A15), U5.19 (A15), U6.19 (A15); also elsewhere on the board
RAM_A17: U3.18 (A16), U4.18 (A16), U5.18 (A16), U6.18 (A16); also elsewhere on the board
RAM_A18: U3.23 (A17), U4.23 (A17), U5.23 (A17), U6.23 (A17); also elsewhere on the board
RAM_A19: U3.28 (A18), U4.28 (A18), U5.28 (A18), U6.28 (A18); also elsewhere on the board
RAM_D0: U3.7 (I/O0), U4.7 (I/O0), U5.7 (I/O0), U6.7 (I/O0); also elsewhere on the board
RAM_D1: U3.8 (I/O1), U4.8 (I/O1), U5.8 (I/O1), U6.8 (I/O1); also elsewhere on the board
RAM_D2: U3.9 (I/O2), U4.9 (I/O2), U5.9 (I/O2), U6.9 (I/O2); also elsewhere on the board
RAM_D3: U3.10 (I/O3), U4.10 (I/O3), U5.10 (I/O3), U6.10 (I/O3); also elsewhere on the board
RAM_D4: U3.13 (I/O4), U4.13 (I/O4), U5.13 (I/O4), U6.13 (I/O4); also elsewhere on the board
RAM_D5: U3.14 (I/O5), U4.14 (I/O5), U5.14 (I/O5), U6.14 (I/O5); also elsewhere on the board
RAM_D6: U3.15 (I/O6), U4.15 (I/O6), U5.15 (I/O6), U6.15 (I/O6); also elsewhere on the board
RAM_D7: U3.16 (I/O7), U4.16 (I/O7), U5.16 (I/O7), U6.16 (I/O7); also elsewhere on the board
RAM_D8: U3.29 (I/O8), U4.29 (I/O8), U5.29 (I/O8), U6.29 (I/O8); also elsewhere on the board
RAM_D9: U3.30 (I/O9), U4.30 (I/O9), U5.30 (I/O9), U6.30 (I/O9); also elsewhere on the board
RAM_D10: U3.31 (I/O10), U4.31 (I/O10), U5.31 (I/O10), U6.31 (I/O10); also elsewhere on the board
RAM_D11: U3.32 (I/O11), U4.32 (I/O11), U5.32 (I/O11), U6.32 (I/O11); also elsewhere on the board
RAM_D12: U3.35 (I/O12), U4.35 (I/O12), U5.35 (I/O12), U6.35 (I/O12); also elsewhere on the board
RAM_D13: U3.36 (I/O13), U4.36 (I/O13), U5.36 (I/O13), U6.36 (I/O13); also elsewhere on the board
RAM_D14: U3.37 (I/O14), U4.37 (I/O14), U5.37 (I/O14), U6.37 (I/O14); also elsewhere on the board
RAM_D15: U3.38 (I/O15), U4.38 (I/O15), U5.38 (I/O15), U6.38 (I/O15); also elsewhere on the board
RAM_LB: U3.39 (~LB), U4.39 (~LB), U5.39 (~LB), U6.39 (~LB); also elsewhere on the board
RAM_OE: U3.41 (~OE), U4.41 (~OE), U5.41 (~OE), U6.41 (~OE); also elsewhere on the board
RAM_SEL0: U3.6 (~CS1); also elsewhere on the board
RAM_SEL1: U4.6 (~CS1); also elsewhere on the board
RAM_SEL2: U5.6 (~CS1); also elsewhere on the board
RAM_SEL3: U6.6 (~CS1); also elsewhere on the board
RAM_UB: U3.40 (~UB), U4.40 (~UB), U5.40 (~UB), U6.40 (~UB); also elsewhere on the board
RAM_WE: U3.17 (~WE), U4.17 (~WE), U5.17 (~WE), U6.17 (~WE); also elsewhere on the board
RESET: IC5.13 (2A1), R1.2, R2.2
RW: IC4.21 (2A7), U2.9 (R/W)
UDS: IC4.16 (2A3), U2.7 (UDS)

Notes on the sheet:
68000 CPU Socket
RAM (512k x 16 each)
5V to 3.3V Bus Switches
CPU Decoupling
RAM Decoupling

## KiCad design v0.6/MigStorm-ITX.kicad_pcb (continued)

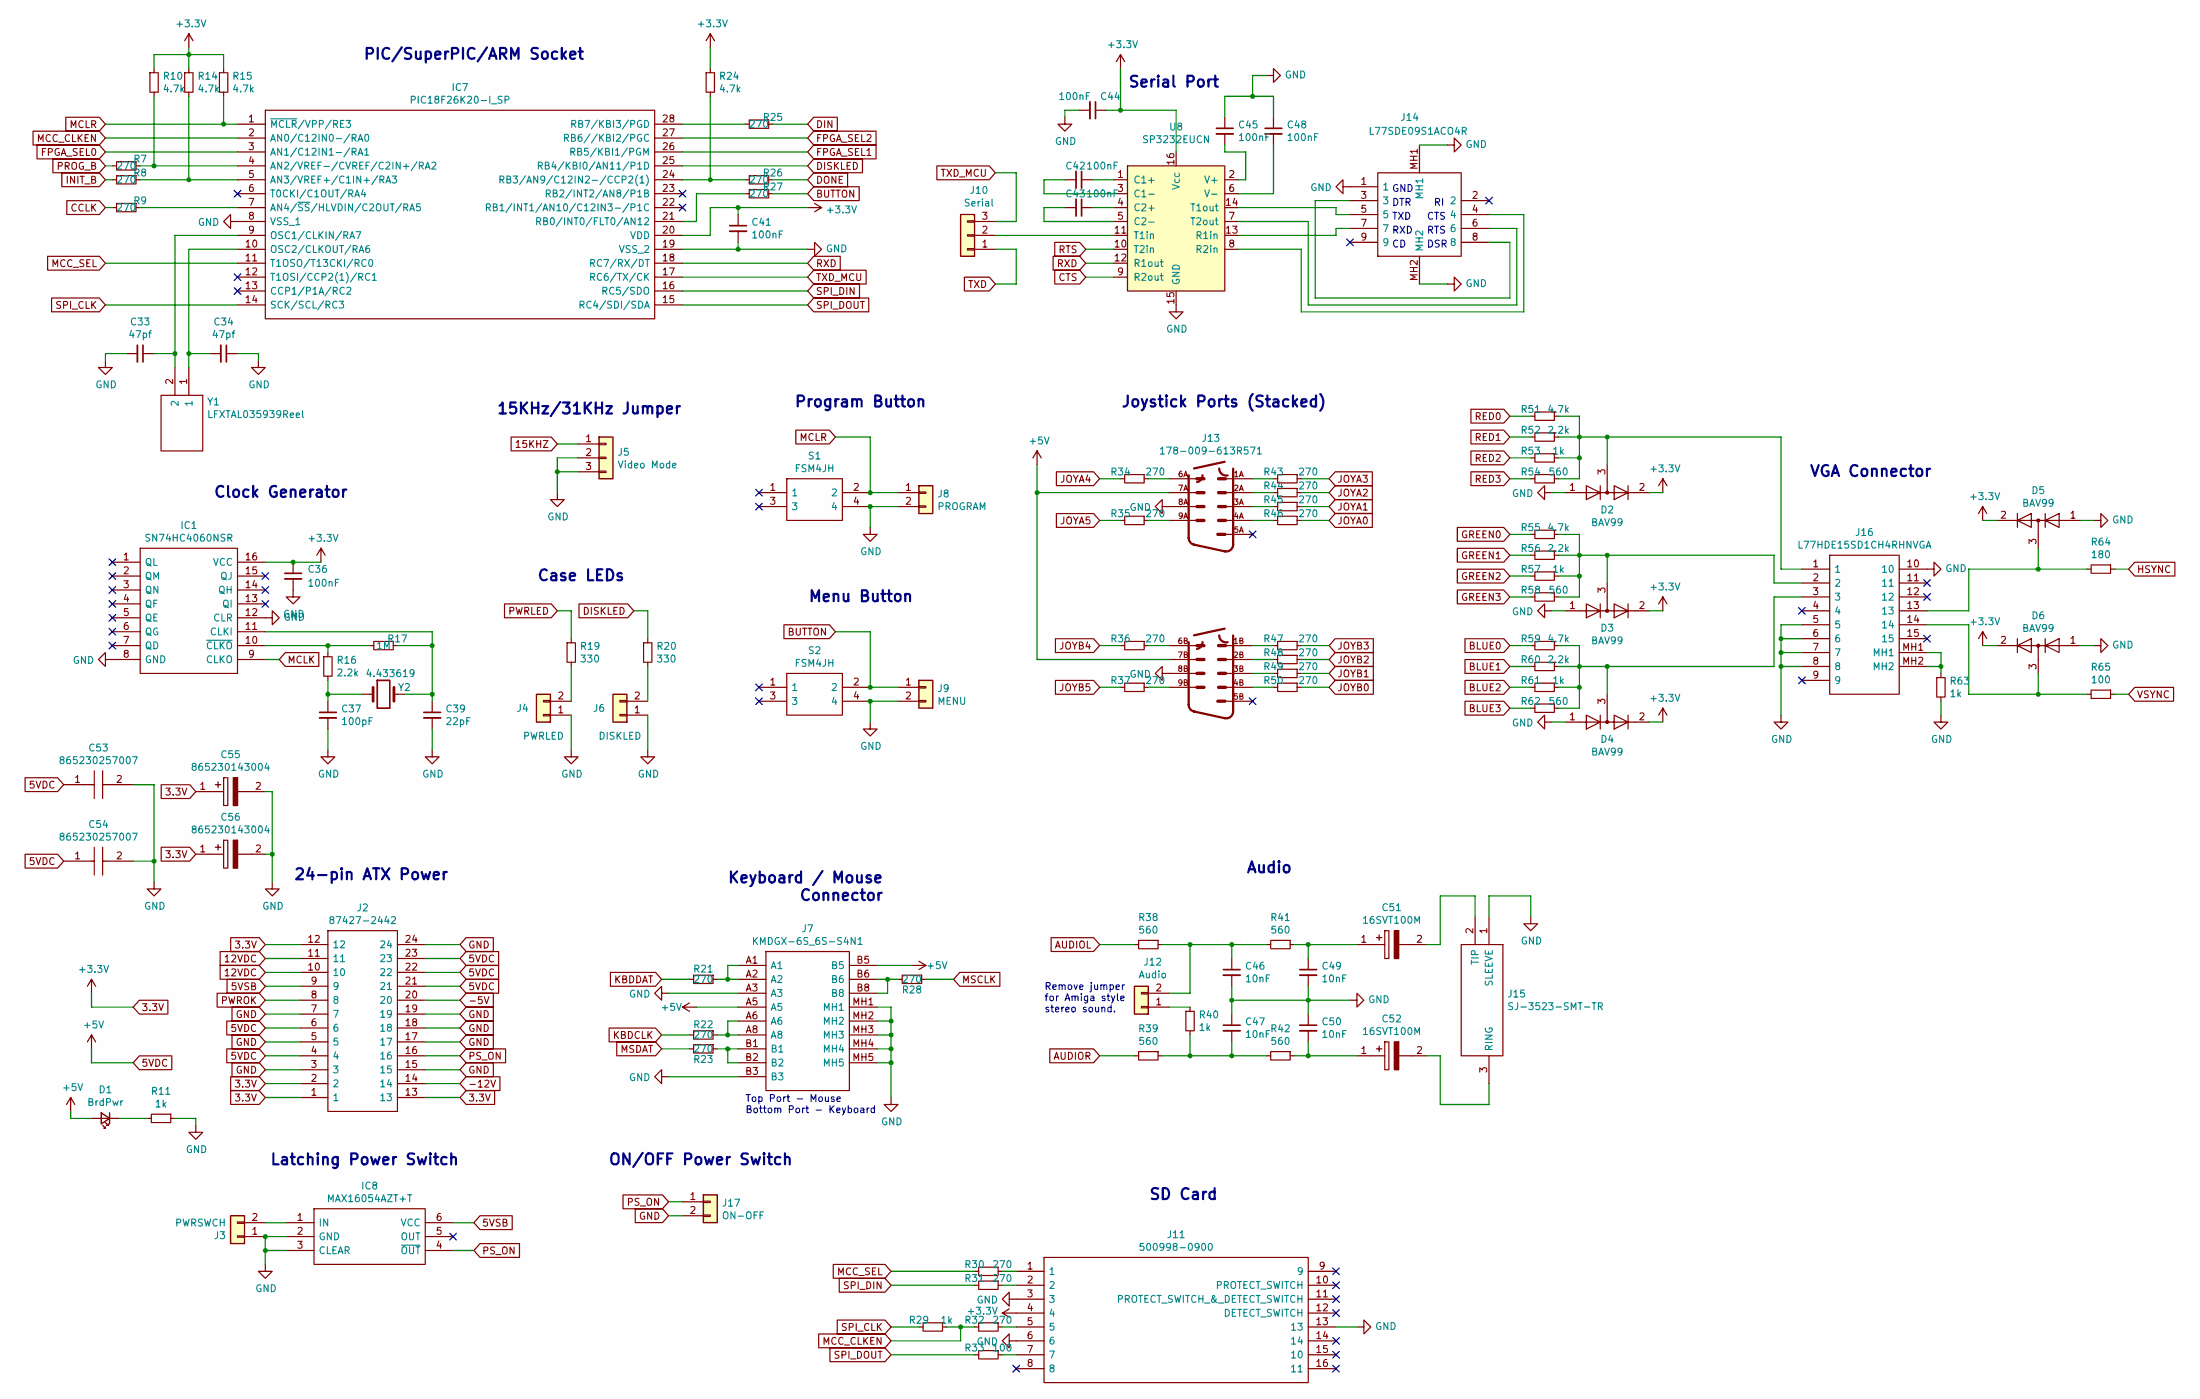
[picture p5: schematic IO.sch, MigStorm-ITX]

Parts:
C33, C34: 47pf; C_0805_2012Metric_Pad1.15x1.40mm_HandSolder
C36, C41, C42, C43, C44, C45, C48: 100nF; C_0805_2012Metric_Pad1.15x1.40mm_HandSolder
C37: 100pF; C_0805_2012Metric_Pad1.15x1.40mm_HandSolder
C39: 22pF; C_0805_2012Metric_Pad1.15x1.40mm_HandSolder
C46, C47, C49, C50: 10nF; C_0805_2012Metric_Pad1.15x1.40mm_HandSolder
C51, C52: 16SVT100M; 16SVPT100M; Mouser Part Number 667-16SVT100M
C53, C54: 865230257007; CAPAE1030X1050N; Mouser Part Number 710-865230257007
C55, C56: 865230143004; CAPAE660X550N; Mouser Part Number 710-865230143004
D1: BrdPwr; LED_D3.0mm
D2, D3, D4, D5, D6: BAV99; SOT-23
IC1: SN74HC4060NSR; SOIC127P780X200-16N; Mouser Part Number 595-SN74HC4060NSR
IC7: PIC18F26K20-I_SP; DIP-28_W7.62mm_Socket; Mouser Part Number 579-PIC18F26K20-I/SP
IC8: MAX16054AZT+T; SOT95P275X110-6N; Mouser Part Number 700-MAX16054AZTT
J2: 87427-2442; Mouser Part Number 538-87427-2442
J3: PWRSWCH; PinHeader_1x02_P2.54mm_Vertical
J4: PWRLED; PinHeader_1x02_P2.54mm_Vertical
J5: Video Mode; PinHeader_1x03_P2.54mm_Vertical
J6: DISKLED; PinHeader_1x02_P2.54mm_Vertical
J7: KMDGX-6S_6S-S4N1; KMDGX6S6SS4N1; Mouser Part Number 806-KMDGX-6S/6S-S4N1
J8: PROGRAM; PinHeader_1x02_P2.54mm_Vertical
J9: MENU; PinHeader_1x02_P2.54mm_Vertical
J10: Serial; PinHeader_1x03_P2.54mm_Vertical
J11: 500998-0900; 5009980900; Mouser Part Number 538-500998-0900
J12: Audio; PinHeader_1x02_P2.54mm_Vertical
J13: 178-009-613R571
J14: L77SDE09S1ACO4R; Mouser Part Number 523-L77SDE09S1ACO4R
J15: SJ-3523-SMT-TR; SJ3523SMTTR; Mouser Part Number 490-SJ-3523-SMT-TR
J16: L77HDE15SD1CH4RHNVGA; Mouser Part Number 523-7HDE15SDH4RHNVGA
J17: ON-OFF; PinHeader_1x02_P2.54mm_Vertical
R7, R8, R9, R21, R22, R23, R25, R26, R27, R28, R30, R31, R32, R34, R35, R36, R37, R43, R44, R45, R46, R47, R48, R49, R50: 270; R_0805_2012Metric_Pad1.15x1.40mm_HandSolder
R10, R14, R15, R24, R51, R55, R59: 4.7k; R_0805_2012Metric_Pad1.15x1.40mm_HandSolder
R11, R29, R40, R53, R57, R61, R63: 1k; R_0805_2012Metric_Pad1.15x1.40mm_HandSolder
R16, R52, R56, R60: 2.2k; R_0805_2012Metric_Pad1.15x1.40mm_HandSolder
R17: 1M; R_0805_2012Metric_Pad1.15x1.40mm_HandSolder
R19, R20: 330; R_0805_2012Metric_Pad1.15x1.40mm_HandSolder
R33, R65: 100; R_0805_2012Metric_Pad1.15x1.40mm_HandSolder
R38, R39, R41, R42, R54, R58, R62: 560; R_0805_2012Metric_Pad1.15x1.40mm_HandSolder
R64: 180; R_0805_2012Metric_Pad1.15x1.40mm_HandSolder
S1, S2: FSM4JH; Mouser Part Number 506-FSM4JH
U8: SP3232EUCN; SOIC-16_3.9x9.9mm_P1.27mm
Y1: LFXTAL035939Reel; LFXTAL020423CUTT; Mouser Part Number 449-LFXTAL035939REEL
Y2: 4.433619; Crystal_SMD_HC49-SD

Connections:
3.3V: C36.1, C41.1, C44.1, C55.1, C56.1, D2.2 (A), D3.2 (A), D4.2 (A), D5.2 (A), D6.2 (A), IC1.16 (VCC), IC7.20 (VDD), J2.1, J2.2, J2.12, J2.13, J11.4, R10.1, R14.1, R15.1, R24.1, U8.16 (Vcc); also elsewhere on the board
5VDC: C53.1, C54.1, D1.2 (A), J2.4, J2.6, J2.21, J2.22, J2.23, J7.A5, J7.B5, J13.7A, J13.7B; also elsewhere on the board
5VSB: IC8.6 (VCC), J2.9
12VDC: J2.10, J2.11
15KHZ: J5.1; also elsewhere on the board
AUDIOL: R38.2; also elsewhere on the board
AUDIOR: R39.2; also elsewhere on the board
BLUE0: R59.2; also elsewhere on the board
BLUE1: R60.2; also elsewhere on the board
BLUE2: R61.2; also elsewhere on the board
BLUE3: R62.2; also elsewhere on the board
BUTTON: J9.1, R27.1, S2.2
CCLK: R9.2; also elsewhere on the board
CTS: U8.9 (R2out); also elsewhere on the board
DIN: R25.1; also elsewhere on the board
DISKLED: IC7.25 (RB4/KBI0/AN11/P1D), R20.1
DONE: R26.1; also elsewhere on the board
FPGA_SEL0: IC7.3 (AN1/C12IN1-/RA1); also elsewhere on the board
FPGA_SEL1: IC7.26 (RB5/KBI1/PGM); also elsewhere on the board
FPGA_SEL2: IC7.27 (RB6//KBI2/PGC); also elsewhere on the board
GND: C33.2, C34.1, C36.2, C37.2, C39.2, C41.2, C44.2, C45.1, C46.2, C47.1, C48.1, C49.2, C50.1, C53.2, C54.2, C55.2, C56.2, D2.1 (K), D3.1 (K), D4.1 (K), D5.1 (K), D6.1 (K), IC1.8 (GND), IC1.12 (CLR), IC7.8 (VSS_1), IC7.19 (VSS_2), IC8.2 (GND), IC8.3 (CLEAR), J2.3, J2.5, J2.7, J2.15, J2.17, J2.18, J2.19, J2.24, J3.1, J4.1, J5.2, J5.3, J6.1, J7.A3, J7.B3, J7.MH1, J7.MH2, J7.MH3, J7.MH4, J7.MH5, J8.2, J9.2, J11.3, J11.6, J11.13, J13.8A, J13.8B, J14.1, J14.MH1, J14.MH2, J15.1 (SLEEVE), J16.5, J16.6, J16.7, J16.8, J16.10, J17.2, R11.1, R63.2, S1.4, S2.4, U8.15 (GND); also elsewhere on the board
GREEN0: R55.2; also elsewhere on the board
GREEN1: R56.2; also elsewhere on the board
GREEN2: R57.2; also elsewhere on the board
GREEN3: R58.2; also elsewhere on the board
HSYNC: R64.1; also elsewhere on the board
INIT_B: R8.2; also elsewhere on the board
JOYA0: R46.1; also elsewhere on the board
JOYA1: R45.1; also elsewhere on the board
JOYA2: R44.1; also elsewhere on the board
JOYA3: R43.1; also elsewhere on the board
JOYA4: R34.2; also elsewhere on the board
JOYA5: R35.2; also elsewhere on the board
JOYB0: R50.1; also elsewhere on the board
JOYB1: R49.1; also elsewhere on the board
JOYB2: R48.1; also elsewhere on the board
JOYB3: R47.1; also elsewhere on the board
JOYB4: R36.2; also elsewhere on the board
JOYB5: R37.2; also elsewhere on the board
KBDCLK: R22.2; also elsewhere on the board
KBDDAT: R21.2; also elsewhere on the board
MCC_CLKEN: IC7.2 (AN0/C12IN0-/RA0), R29.1, R32.2
MCC_SEL: IC7.11 (T1OSO/T13CKI/RC0), R30.2
MCLK: IC1.9 (CLKO); also elsewhere on the board
MCLR: IC7.1 (~MCLR~/VPP/RE3), J8.1, R15.2, S1.2
MSCLK: R28.1; also elsewhere on the board
MSDAT: R23.2; also elsewhere on the board
unnamed: C33.1, IC7.9 (OSC1/CLKIN/RA7), Y1.2
unnamed: C34.2, IC7.10 (OSC2/CLKOUT/RA6), Y1.1
unnamed: C37.1, R16.2, Y2.1
unnamed: C39.1, IC1.11 (CLKI), R17.1, Y2.2
unnamed: C42.1, U8.1 (C1+)
unnamed: C42.2, U8.3 (C1-)
unnamed: C43.1, U8.4 (C2+)
unnamed: C43.2, U8.5 (C2-)
unnamed: C45.2, U8.2 (V+)
unnamed: C46.1, J12.2, R38.1, R41.2
unnamed: C47.2, R39.1, R40.2, R42.2
unnamed: C48.2, U8.6 (V-)
unnamed: C49.1, C51.1, R41.1
unnamed: C50.2, C52.1, R42.1
unnamed: C51.2, J15.2 (TIP)
unnamed: C52.2, J15.3 (RING)
unnamed: D1.1 (K), R11.2
unnamed: D2.3 (K), J16.1, R51.1, R52.1, R53.1, R54.1
unnamed: D3.3 (K), J16.2, R55.1, R56.1, R57.1, R58.1
unnamed: D4.3 (K), J16.3, R59.1, R60.1, R61.1, R62.1
unnamed: D5.3 (K), J16.13, R64.2
unnamed: D6.3 (K), J16.14, R65.2
unnamed: IC1.10 (~CLKO), R16.1, R17.2
unnamed: IC7.4 (AN2/VREF-/CVREF/C2IN+/RA2), R7.1, R10.2
unnamed: IC7.5 (AN3/VREF+/C1IN+/RA3), R8.1, R14.2
unnamed: IC7.7 (AN4/~SS~/HLVDIN/C2OUT/RA5), R9.1
unnamed: IC7.21 (RB0/INT0/FLT0/AN12), R27.2
unnamed: IC7.24 (RB3/AN9/C12IN2-/CCP2(1)), R24.2, R26.2
unnamed: IC7.28 (RB7/KBI3/PGD), R25.2
unnamed: IC8.1 (IN), J3.2
unnamed: J4.2, R19.2
unnamed: J6.2, R20.2
unnamed: J7.A1, J7.A2, R21.1
unnamed: J7.A6, J7.A8, R22.1
unnamed: J7.B1, J7.B2, R23.1
unnamed: J7.B6, J7.B8, R28.2
unnamed: J10.2, U8.11 (T1in)
unnamed: J11.1, R30.1
unnamed: J11.2, R31.1
unnamed: J11.5, R32.1
unnamed: J11.7, R33.1
unnamed: J12.1, R40.1
unnamed: J13.1A, R43.2
unnamed: J13.1B, R47.2
unnamed: J13.2A, R44.2
unnamed: J13.2B, R48.2
unnamed: J13.3A, R45.2
unnamed: J13.3B, R49.2
unnamed: J13.4A, R46.2
unnamed: J13.4B, R50.2
unnamed: J13.6A, R34.1
unnamed: J13.6B, R36.1
unnamed: J13.9A, R35.1
unnamed: J13.9B, R37.1
unnamed: J14.3, J14.8
unnamed: J14.4, U8.8 (R2in)
unnamed: J14.5, U8.14 (T1out)
unnamed: J14.6, U8.7 (T2out)
unnamed: J14.7, U8.13 (R1in)
unnamed: J16.MH1, J16.MH2, R63.1
PROG_B: R7.2; also elsewhere on the board
PS_ON: IC8.4 (~OUT), J2.16, J17.1
PWRLED: R19.1; also elsewhere on the board
RED0: R51.2; also elsewhere on the board
RED1: R52.2; also elsewhere on the board
RED2: R53.2; also elsewhere on the board
RED3: R54.2; also elsewhere on the board
RTS: U8.10 (T2in); also elsewhere on the board
RXD: IC7.18 (RC7/RX/DT), U8.12 (R1out); also elsewhere on the board
SPI_CLK: IC7.14 (SCK/SCL/RC3), R29.2; also elsewhere on the board
SPI_DIN: IC7.16 (RC5/SDO), R31.2; also elsewhere on the board
SPI_DOUT: IC7.15 (RC4/SDI/SDA), R33.2; also elsewhere on the board
TXD: J10.1; also elsewhere on the board
TXD_MCU: IC7.17 (RC6/TX/CK), J10.3
VSYNC: R65.1; also elsewhere on the board

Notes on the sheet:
PIC/SuperPIC/ARM Socket
Clock Generator
15KHz/31KHz Jumper
Case LEDs
Menu Button
Program Button
24-pin ATX Power
Latching Power Switch
Keyboard / Mouse Connector
Serial Port
GND
RXD
TXD
DTR
CTS
RTS
DSR
Joystick Ports (Stacked)
Audio
Remove jumper for Amiga style stereo sound.
SD Card
VGA Connector
ON/OFF Power Switch
Top Port - Mouse Bottom Port - Keyboard

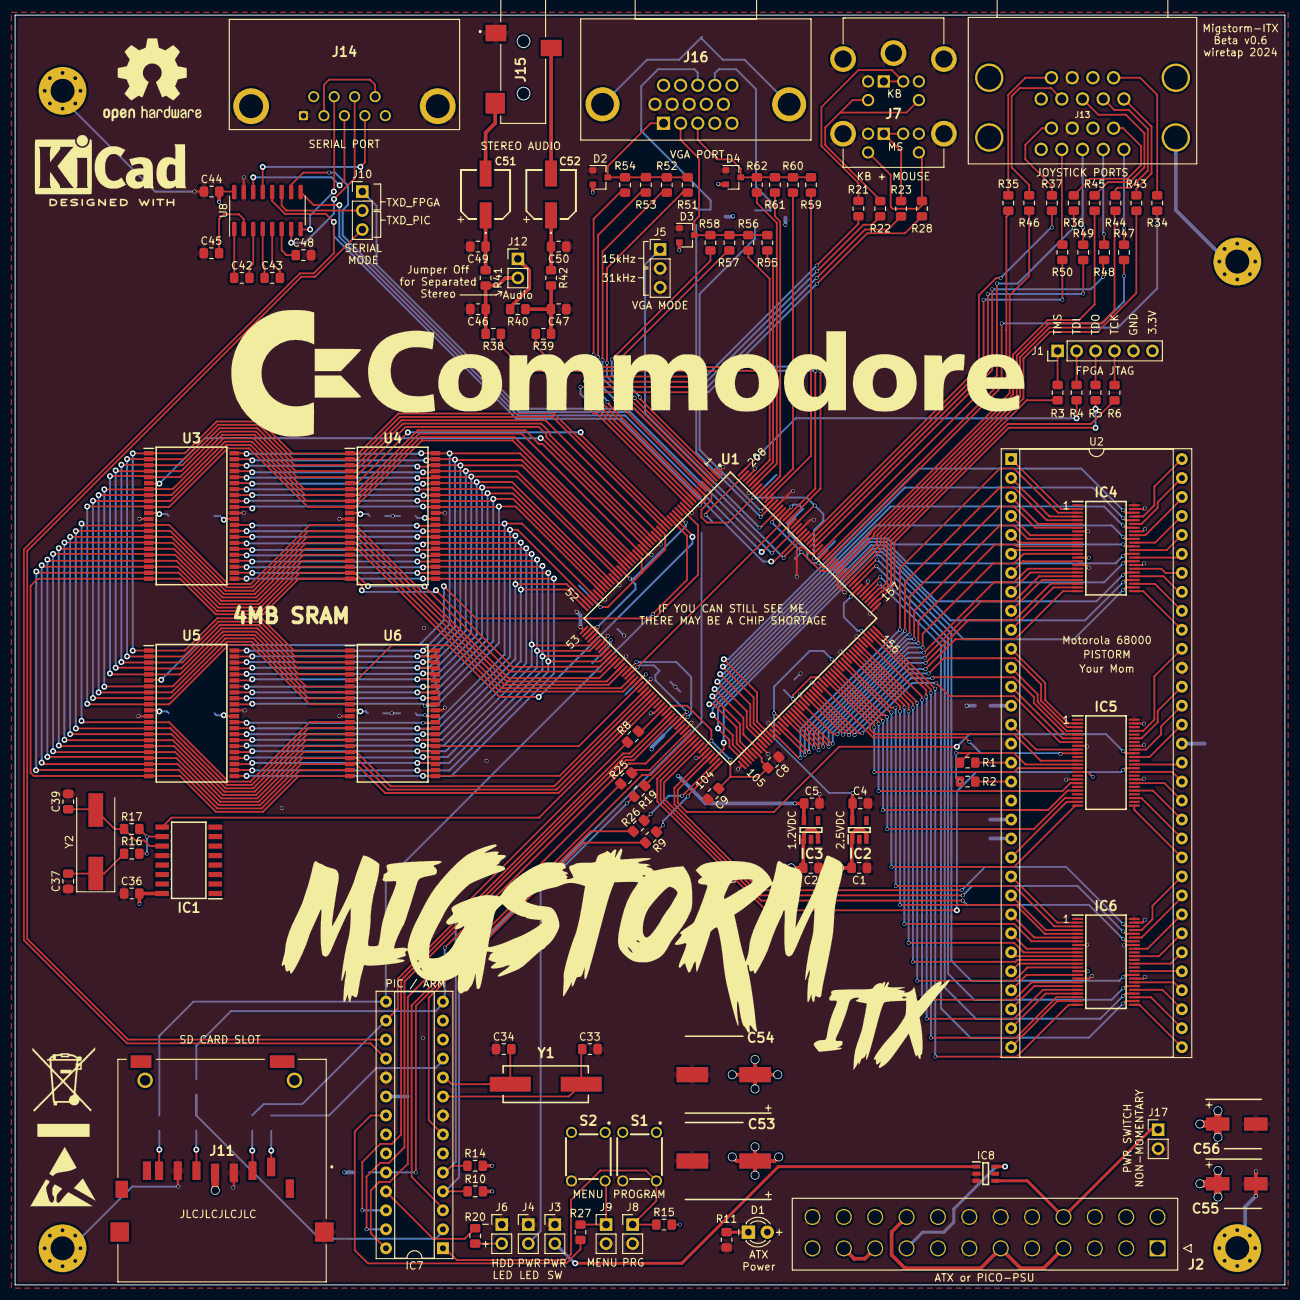
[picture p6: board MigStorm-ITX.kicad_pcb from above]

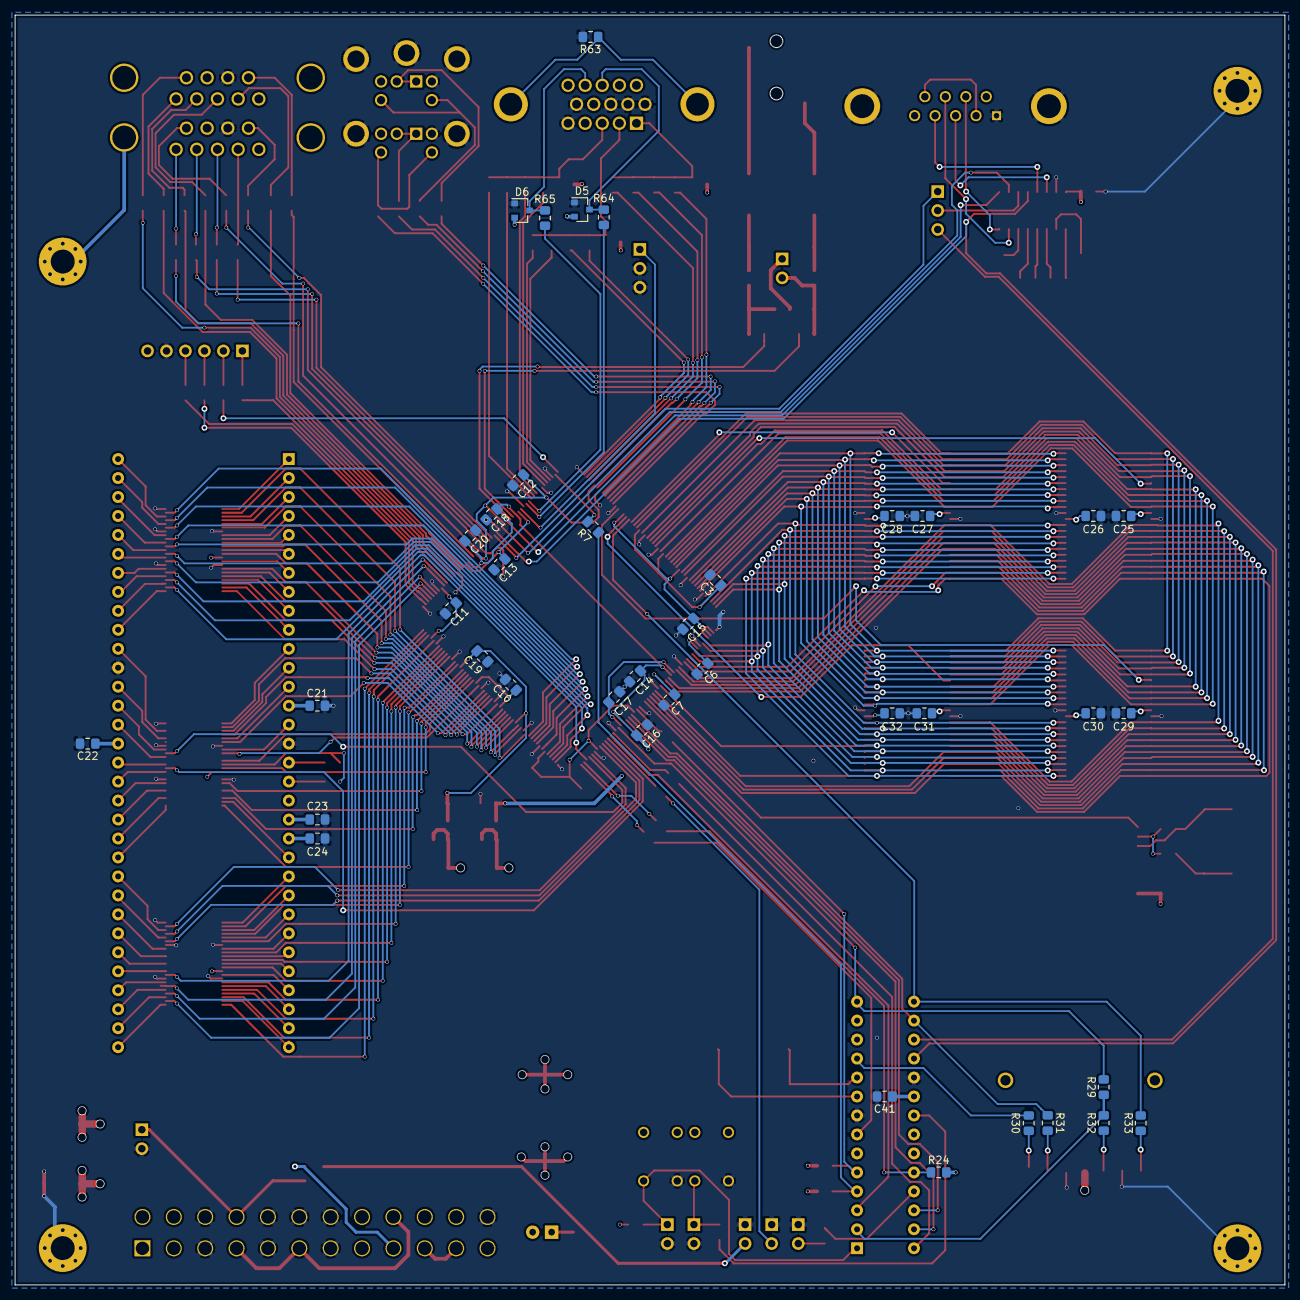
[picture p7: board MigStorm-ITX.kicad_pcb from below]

Board: 4 copper layers, 170.0 x 170.0 mm, 157 parts (39 on the bottom side), 282 nets.

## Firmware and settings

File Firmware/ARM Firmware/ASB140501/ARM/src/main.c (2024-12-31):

/****************************************************************************
*  Copyright (c) 2006 by Michael Fischer. All rights reserved.
*
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
*  1. Redistributions of source code must retain the above copyright 
*     notice, this list of conditions and the following disclaimer.
*  2. Redistributions in binary form must reproduce the above copyright
*     notice, this list of conditions and the following disclaimer in the 
*     documentation and/or other materials provided with the distribution.
*  3. Neither the name of the author nor the names of its contributors may 
*     be used to endorse or promote products derived from this software 
*     without specific prior written permission.
*
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
****************************************************************************
*  History:
*
*  30.03.06  mifi   First Version for Insight tutorial
*  26.01.08  mifi   Added variable "d" to test const variable.
*  13.02.10  mifi   Added floating point too.
****************************************************************************/
#define __MAIN_C__
// 2008-10-04   - porting to ARM
// 2008-10-06   - support for 4 floppy drives
// 2008-10-30   - hdd write support
// 2009-05-01   - subdirectory support
// 2009-06-26   - SDHC and FAT32 support
// 2009-08-10   - hardfile selection
// 2009-09-11   - minor changes to hardware initialization routine
// 2009-10-10   - any length fpga core file support
// 2009-11-14   - adapted floppy gap size
//              - changes to OSD labels
// 2009-12-24   - updated version number
// 2010-01-09   - changes to floppy handling
// 2010-07-28   - improved menu button handling
//              - improved FPGA configuration routines
//              - added support for OSD vsync
// 2010-08-15   - support for joystick emulation
// 2010-08-18   - clean-up
// 2012-02-11	- ported to GNU Toolchain
// 2014-04-24   - added page wide file list scroll at joystick left/right
//              - removed OSD fdd error message (for WOMM87/AW72)
//              - added FPGA core file selection (core upload working yet)
#include "AT91SAM7S256.h"
//#include "stdio.h"
//#include "string.h"
#include "printf.h"
#include "stringlight.h"
#include "errors.h"
#include "hardware.h"
#include "MMC.h"
#include "FAT.h"
#include "OSD.h"
#include "FPGA.h"
#include "FDD.h"
#include "HDD.h"
#include "firmware.h"
#include "menu.h"
#include "config.h"

const char version[] = {"$VER:ASB140501"};

extern char *config_filter_msg[];
extern char *config_memory_chip_msg[];
extern char *config_memory_slow_msg[];
extern char *config_scanline_msg[];

configTYPE config;
fileTYPE file;

extern hdfTYPE hdf[2];

unsigned char Error;
char s[40];

void FatalError(unsigned long error)
{
    unsigned long i;

    printf("Fatal error: %lu\r", error);

    while (1)
    {
        for (i = 0; i < error; i++)
        {
            DISKLED_ON;
            WaitTimer(250);
            DISKLED_OFF;
            WaitTimer(250);
        }
        WaitTimer(1000);
    }
}

char UploadKickstart(char *name)
{
    char filename[12];
    strncpy(filename, name, 8); // copy base name
    strcpy(&filename[8], "ROM"); // add extension

    if (FileOpen(&file, filename))
    {
        if (file.size == 0x80000)
        { // 512KB Kickstart ROM
            BootPrint("Uploading 512 KB Kickstart...");
            BootUpload(&file, 0xF8, 0x08);
            return(1);
        }
        else if (file.size == 0x40000)
        { // 256KB Kickstart ROM
            BootPrint("Uploading 256 KB Kickstart...");
            BootUpload(&file, 0xF8, 0x04);
            return(1);
        }
        else
        {
            BootPrint("Unsupported ROM file size!");
        }
    }
    else
    {
        sprintf(s, "No \"%s\" file!", filename);
        BootPrint(s);
    }
    return(0);
}

unsigned char LoadConfiguration(char *filename)
{
    static const char config_id[] = "MNMGCFG0";

    // load configurastion data
    if (FileOpen(&file, filename))
    {
        printf("Configuration file size: %lu\r", file.size);
        if (file.size == sizeof(config))
        {
            FileRead(&file, sector_buffer);

            // check file id and version
            if (strncmp((char*)sector_buffer, config_id, sizeof(config.id)) == 0)
            {
                memcpy((void*)&config, (void*)sector_buffer, sizeof(config));
                return(1);
            }
            else
                printf("Wrong configuration file format!\r");
        }
        else
            printf("Wrong configuration file size: %lu (expected: %u)\r", file.size, sizeof(config));
    }
    else
        printf("Can not open configuration file!\r");

    // set default configuration
    memset((void*)&config, sizeof(config), 0);
    strncpy(config.id, config_id, sizeof(config.id));
    strncpy(config.kickstart.name, "KICK    ", sizeof(config.kickstart.name));
    config.kickstart.long_name[0] = 0;
    config.corefile.long_name[0] = 0;
    config.memory = 0x05;
    config.hardfile[0].enabled = 1;
    strncpy(config.hardfile[0].name, "HARDFILE", sizeof(config.hardfile[0].name));
    return(0);
}

unsigned char SaveConfiguration(char *filename)
{
    // save configuration data
    if (FileOpen(&file, filename))
    {
        printf("Configuration file size: %lu\r", file.size);
        if (file.size != sizeof(config))
        {
            file.size = sizeof(config);
            if (!UpdateEntry(&file))
                return(0);
        }

        memset((void*)&sector_buffer, 0, sizeof(sector_buffer));
        memcpy((void*)&sector_buffer, (void*)&config, sizeof(config));
        FileWrite(&file, sector_buffer);
        return(1);
    }
    else
    {
        printf("Configuration file not found!\r");
        printf("Trying to create a new one...\r");
        strncpy(file.name, filename, 11);
        file.attributes = 0;
        file.size = sizeof(config);
        if (FileCreate(0, &file))
        {
            printf("File created.\r");
            printf("Trying to write new data...\r");
            memset((void*)sector_buffer, 0, sizeof(sector_buffer));
            memcpy((void*)sector_buffer, (void*)&config, sizeof(config));

            if (FileWrite(&file, sector_buffer))
            {
                printf("File written successfully.\r");
                return(1);
            }
            else
                printf("File write failed!\r");
        }
        else
            printf("File creation failed!\r");
    }
    return(0);
}

void HandleFpga(void)
{
    unsigned char  c1, c2;

    EnableFpga();
    c1 = SPI(0); // cmd request and drive number
    c2 = SPI(0); // track number
    SPI(0);
    SPI(0);
    SPI(0);
    SPI(0);
    DisableFpga();

    HandleFDD(c1, c2);
    HandleHDD(c1, c2);

    UpdateDriveStatus();
}


int main(void)
{
    unsigned char rc;
    unsigned char key;
    unsigned long time;
    unsigned short spiclk;
    //unsigned char CSD[16];
    // init_hardware();

    DISKLED_ON;

    Timer_Init();
    init_printf(NULL, USART_Putc); // Initialise printf
    USART_Init(115200);

    printf("\rMinimig by Dennis van Weeren");
    printf("\rARM Controller by Jakub Bednarski\r\r");
    printf("Version %s\r\r", version+5);
    printf("\rGCC Port\r\r");
    SPI_Init();

    if (CheckButton()) // if menu button pressed fall back to slow SPI mode
       SetSPIMode(SPIMODE_NORMAL);

    if (!MMC_Init())
        FatalError(1);

    spiclk = MCLK / ((AT91C_SPI_CSR[0] & AT91C_SPI_SCBR) >> 8) / 1000000;
    printf("spiclk: %u MHz\r", spiclk);

    if (!FindDrive())
        FatalError(2);

    ChangeDirectory(DIRECTORY_ROOT);

    time = GetTimer(0);
    if ((*AT91C_PIOA_PDSR & 1))
    {
    if (ConfigureFpga("MINIMIG1BIN"))
    {
        time = GetTimer(0) - time;
        printf("FPGA configured in %lu ms\r", time >> 20);
    }
    else
    {
        printf("FPGA configuration failed\r");
        FatalError(3);
    }
    }
    WaitTimer(100); // let's wait some time till reset is inactive so we can get a valid keycode

    key = OsdGetCtrl();
    rc = LoadConfiguration("MINIMIG CFG");

    if (key == KEY_F1)
       config.chipset |= CONFIG_NTSC; // force NTSC mode if F1 pressed

    if (key == KEY_F2)
       config.chipset &= ~CONFIG_NTSC; // force PAL mode if F2 pressed

    ConfigChipset(config.chipset | CONFIG_TURBO); // set CPU in turbo mode

    OsdReset(RESET_BOOTLOADER);

    ConfigFloppy(1, CONFIG_FLOPPY2X); // set floppy speed

    sprintf(s, "** ARM firmware %s **\n", version + 5);
    BootPrint(s);

    sprintf(s, "SPI clock: %u MHz\n", spiclk);
    BootPrint(s);

    if (!rc)
        BootPrint("Configuration file not found...\n");

    sprintf(s, "CPU clock     : %s", config.chipset & 0x01 ? "turbo" : "normal");
    BootPrint(s);
    sprintf(s, "Chip RAM size : %s", config_memory_chip_msg[config.memory & 0x03]);
    BootPrint(s);
    sprintf(s, "Slow RAM size : %s", config_memory_slow_msg[config.memory >> 2 & 0x03]);
    BootPrint(s);

    sprintf(s, "Floppy drives : %u", config.floppy.drives + 1);
    BootPrint(s);
    sprintf(s, "Floppy speed  : %s", config.floppy.speed ? "fast": "normal");
    BootPrint(s);

    BootPrint("");

    if (!UploadKickstart(config.kickstart.name))
    {
        strcpy(config.kickstart.name, "KICK    ");
        if (!UploadKickstart(config.kickstart.name))
            FatalError(6);
    }

    if (!CheckButton() && !config.disable_ar3) // if menu button pressed don't load Action Replay
    {
        if (FileOpen(&file, "AR3     ROM"))
        {
            if (file.size == 0x40000)
            { // 256 KB Action Replay 3 ROM
                BootPrint("\nUploading Action Replay ROM...");
                BootUpload(&file, 0x40, 0x04);
                ClearMemory(0x440000, 0x40000);
            }
            else
            {
                BootPrint("\nUnsupported AR3.ROM file size!!!");
                FatalError(6);
            }
        }
    }

    if (OpenHardfile(0))
    {

        sprintf(s, "\nHardfile 0: %.8s.%.3s", hdf[0].file.name, &hdf[0].file.name[8]);
        BootPrint(s);
        sprintf(s, "CHS: %u.%u.%u", hdf[0].cylinders, hdf[0].heads, hdf[0].sectors);
        BootPrint(s);
        sprintf(s, "Size: %lu MB", ((((unsigned long) hdf[0].cylinders) * hdf[0].heads * hdf[0].sectors) >> 11));
        BootPrint(s);
    }

    if (OpenHardfile(1))
    {

        sprintf(s, "\nHardfile 1: %.8s.%.3s", hdf[1].file.name, &hdf[1].file.name[8]);
        BootPrint(s);
        sprintf(s, "CHS: %u.%u.%u", hdf[1].cylinders, hdf[1].heads, hdf[1].sectors);
        BootPrint(s);
        sprintf(s, "Size: %lu MB", ((((unsigned long) hdf[1].cylinders) * hdf[1].heads * hdf[1].sectors) >> 11));
        BootPrint(s);
    }

    sprintf(s, "\nA600 IDE HDC is %s.", config.enable_ide ? "enabled" : "disabled");
    BootPrint(s);
    sprintf(s, "Master HDD is %s.", config.hardfile[0].present ? config.hardfile[0].enabled ? "enabled" : "disabled" : "not present");
    BootPrint(s);
    sprintf(s, "Slave HDD is %s.", config.hardfile[1].present ? config.hardfile[1].enabled ? "enabled" : "disabled" : "not present");
    BootPrint(s);

    if (cluster_size < 64)
    {
        BootPrint("\n***************************************************");
        BootPrint(  "*  It's recommended to reformat your memory card  *");
        BootPrint(  "*   using 32 KB clusters to improve performance   *");
        BootPrint(  "***************************************************");
    }

    ConfigIDE(config.enable_ide, config.hardfile[0].present && config.hardfile[0].enabled, config.hardfile[1].present && config.hardfile[1].enabled);
    WaitTimer(1000);

    printf("Bootloading is complete.\r");

    BootPrint("\nExiting bootloader...");
    WaitTimer(500);

    ConfigMemory(config.memory);
    ConfigFloppy(config.floppy.drives, config.floppy.speed);

    BootExit();

    ConfigChipset(config.chipset);
    ConfigFilter(config.filter.lores, config.filter.hires);
    ConfigScanlines(config.scanlines);

    while (1)
    {
        HandleFpga();
        HandleUI();
    }


  /*
   * This return here make no sense.
   * But to prevent the compiler warning:
   * "return type of 'main' is not 'int'
   * we use an int as return :-)
   */ 
  return(0);
}

/*** EOF ***/

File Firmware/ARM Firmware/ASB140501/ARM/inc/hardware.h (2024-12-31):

#define MCLK 48000000
#define FWS 1 // Flash wait states

#define DISKLED    AT91C_PIO_PA10
#define MMC_CLKEN  AT91C_PIO_PA24
#define MMC_SEL    AT91C_PIO_PA27
#define DIN AT91C_PIO_PA20
#define CCLK AT91C_PIO_PA4
#define PROG_B AT91C_PIO_PA9
#define INIT_B AT91C_PIO_PA7
#define DONE AT91C_PIO_PA8
#define FPGA0 AT91C_PIO_PA26
#define FPGA1 AT91C_PIO_PA25
#define FPGA2 AT91C_PIO_PA15
#define BUTTON AT91C_PIO_PA28

#define DISKLED_ON *AT91C_PIOA_SODR = DISKLED;
#define DISKLED_OFF *AT91C_PIOA_CODR = DISKLED;
// #define RAMFUNC   __attribute__ ((section(".ramsection")))
#define RAMFUNC __attribute__ ((section (".text.fastcode")))
void init_hardware(void);
void USART_Init(unsigned long baudrate);
void USART_Write(unsigned char c);
void USART_Putc(void* p, char c);
RAMFUNC void SPI_Init(void);
RAMFUNC unsigned char SPI(unsigned char outByte);
RAMFUNC void SPI_Wait4XferEnd(void);
RAMFUNC void EnableCard(void);
RAMFUNC void DisableCard(void);
void EnableFpga(void);
void DisableFpga(void);
void EnableOsd(void);
void DisableOsd(void);
unsigned long CheckButton(void);
void Timer_Init(void);
unsigned long GetTimer(unsigned long offset);
unsigned long CheckTimer(unsigned long t);
void WaitTimer(unsigned long time);

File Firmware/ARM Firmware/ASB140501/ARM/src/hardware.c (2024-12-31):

 /*
Copyright 2008, 2009 Jakub Bednarski

This file is part of Minimig

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
You should have received a copy of the GNU General Public License
along with this program.  If not, see <http://www.gnu.org/licenses/>.
*/

#include "AT91SAM7S256.h"
#include "stdio.h"
#include "hardware.h"

void init_hardware(void)
{

    *AT91C_WDTC_WDMR = AT91C_WDTC_WDDIS; // disable watchdog
    *AT91C_RSTC_RMR = (0xA5 << 24) | AT91C_RSTC_URSTEN;   // enable external user reset input
    *AT91C_MC_FMR = FWS << 8; // Flash wait states

    // configure clock generator
    *AT91C_CKGR_MOR = AT91C_CKGR_MOSCEN | (40 << 8);  
    while (!(*AT91C_PMC_SR & AT91C_PMC_MOSCS));

    *AT91C_CKGR_PLLR = AT91C_CKGR_OUT_0 | AT91C_CKGR_USBDIV_1 | (25 << 16) | (40 << 8) | 5; // DIV=5 MUL=26 USBDIV=1 (2) PLLCOUNT=40
    while (!(*AT91C_PMC_SR & AT91C_PMC_LOCK));

    *AT91C_PMC_MCKR = AT91C_PMC_PRES_CLK_2; // master clock register: clock source selection
    while (!(*AT91C_PMC_SR & AT91C_PMC_MCKRDY));

    *AT91C_PMC_MCKR = AT91C_PMC_CSS_PLL_CLK | AT91C_PMC_PRES_CLK_2; // master clock register: clock source selection
    while (!(*AT91C_PMC_SR & AT91C_PMC_MCKRDY));

    *AT91C_PIOA_PER = 0xFFFFFFFF; // enable pio
    *AT91C_PIOA_CODR = DISKLED; // clear output data register
    *AT91C_PIOA_SODR = MMC_SEL | MMC_CLKEN | CCLK | DIN | PROG_B | FPGA0 | FPGA1 | FPGA2; // set output data register

    // output enable register
    *AT91C_PIOA_OER = DISKLED | MMC_SEL | CCLK | DIN | PROG_B | FPGA0 | FPGA1 | FPGA2;
    // pull-up disable register
    *AT91C_PIOA_PPUDR = DISKLED | MMC_SEL | MMC_CLKEN  | CCLK | DIN | PROG_B | INIT_B | DONE | FPGA0 | FPGA1 | FPGA2;

    // Enable peripheral clock in the PMC
    AT91C_BASE_PMC->PMC_PCER = 1 << AT91C_ID_PIOA;
    *AT91C_PIOA_PPUER = 1;

}

void USART_Init(unsigned long baudrate)
{
    // Configure PA5 and PA6 for USART0 use
    AT91C_BASE_PIOA->PIO_PDR = AT91C_PA5_RXD0 | AT91C_PA6_TXD0;

    // Enable the peripheral clock in the PMC
    AT91C_BASE_PMC->PMC_PCER = 1 << AT91C_ID_US0;

    // Reset and disable receiver & transmitter
    AT91C_BASE_US0->US_CR = AT91C_US_RSTRX | AT91C_US_RSTTX | AT91C_US_RXDIS | AT91C_US_TXDIS;

    // Configure USART0 mode
    AT91C_BASE_US0->US_MR = AT91C_US_USMODE_NORMAL | AT91C_US_CLKS_CLOCK | AT91C_US_CHRL_8_BITS | AT91C_US_PAR_NONE | AT91C_US_NBSTOP_1_BIT | AT91C_US_CHMODE_NORMAL;

    // Configure USART0 rate
    AT91C_BASE_US0->US_BRGR = MCLK / 16 / baudrate;

    // Enable receiver & transmitter
    AT91C_BASE_US0->US_CR = AT91C_US_RXEN | AT91C_US_TXEN;
}

RAMFUNC void USART_Write(unsigned char c)
{
    while (!(AT91C_BASE_US0->US_CSR & AT91C_US_TXEMPTY));
    AT91C_BASE_US0->US_THR = c;
}

void USART_Putc(void* p, char c) {
  while (!(AT91C_BASE_US0->US_CSR & AT91C_US_TXEMPTY));
  AT91C_BASE_US0->US_THR = c;
}

signed int fputc(signed int c, FILE *pStream)
{
    if ((pStream == stdout) || (pStream == stderr))
    {
        USART_Write((unsigned char)c);
        return c;
    }

    return EOF;
}

void SPI_Init()
{
    // Enable the peripheral clock in the PMC
    AT91C_BASE_PMC->PMC_PCER = 1 << AT91C_ID_SPI;

    // Enable SPI interface
    *AT91C_SPI_CR = AT91C_SPI_SPIEN;

    // SPI Mode Register
    *AT91C_SPI_MR = AT91C_SPI_MSTR | AT91C_SPI_MODFDIS  | (0x0E << 16);

    // SPI CS register
    AT91C_SPI_CSR[0] = AT91C_SPI_CPOL | (48 << 8) | (0x00 << 16) | (0x01 << 24);

    // Configure pins for SPI use
    AT91C_BASE_PIOA->PIO_PDR = AT91C_PA14_SPCK | AT91C_PA13_MOSI | AT91C_PA12_MISO;
}

//#pragma section_code_init
RAMFUNC unsigned char SPI(unsigned char outByte)
{
    unsigned long t = *AT91C_SPI_RDR;
    while (!(*AT91C_SPI_SR & AT91C_SPI_TDRE));
    *AT91C_SPI_TDR = outByte;
    while (!(*AT91C_SPI_SR & AT91C_SPI_RDRF));
    return((unsigned char)*AT91C_SPI_RDR);
}
RAMFUNC void SPI_Wait4XferEnd()
{
    while (!(*AT91C_SPI_SR & AT91C_SPI_TXEMPTY));
}
// __attribute__((noinline))


RAMFUNC void EnableCard()
{
    *AT91C_PIOA_CODR = MMC_SEL;  // clear output (MMC chip select enabled)
}

RAMFUNC void DisableCard()
{
    SPI_Wait4XferEnd();
    *AT91C_PIOA_SODR = MMC_SEL;  // set output (MMC chip select disabled)
    SPI(0xFF);
    SPI_Wait4XferEnd();
}

//#pragma section_no_code_init

void EnableFpga()
{
    *AT91C_PIOA_CODR = FPGA0;  // clear output
}

void DisableFpga()
{
    SPI_Wait4XferEnd();
    *AT91C_PIOA_SODR = FPGA0;  // set output
}

void EnableOsd()
{
    *AT91C_PIOA_CODR = FPGA1;  // clear output
}

void DisableOsd()
{
    SPI_Wait4XferEnd();
    *AT91C_PIOA_SODR = FPGA1;  // set output
}

unsigned long CheckButton(void)
{
    return((~*AT91C_PIOA_PDSR) & BUTTON);
}

void Timer_Init(void)
{
    *AT91C_PITC_PIMR = AT91C_PITC_PITEN | ((MCLK / 16 / 1000 - 1) & AT91C_PITC_PIV); // counting period 1ms
}

unsigned long GetTimer(unsigned long offset)
{
    unsigned long systimer = (*AT91C_PITC_PIIR & AT91C_PITC_PICNT);
    systimer += offset << 20;
    return (systimer); // valid bits [31:20]
}

unsigned long CheckTimer(unsigned long time)
{
    unsigned long systimer = (*AT91C_PITC_PIIR & AT91C_PITC_PICNT);
    time -= systimer;
    return(time > (1 << 31));
}

void WaitTimer(unsigned long time)
{
    time = GetTimer(time);
    while (!CheckTimer(time));
}

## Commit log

2023-05-09 Interactive BOM for v0.4
2023-10-07 Upload rev 0.5
    Update silk screen for polarity references upon request. Updated iBOM and BOM.
    [BOM.xlsx, CPU-RAM.sch, FPGA.sch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]

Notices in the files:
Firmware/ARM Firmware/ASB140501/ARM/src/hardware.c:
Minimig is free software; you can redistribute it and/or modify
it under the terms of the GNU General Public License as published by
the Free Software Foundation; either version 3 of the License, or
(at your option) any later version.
